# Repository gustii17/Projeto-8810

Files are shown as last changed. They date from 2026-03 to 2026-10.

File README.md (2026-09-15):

# Projeto 8810
`Projeto 8810 - Módulo Didático de Eletrônica Digital`

<h1 align="center">
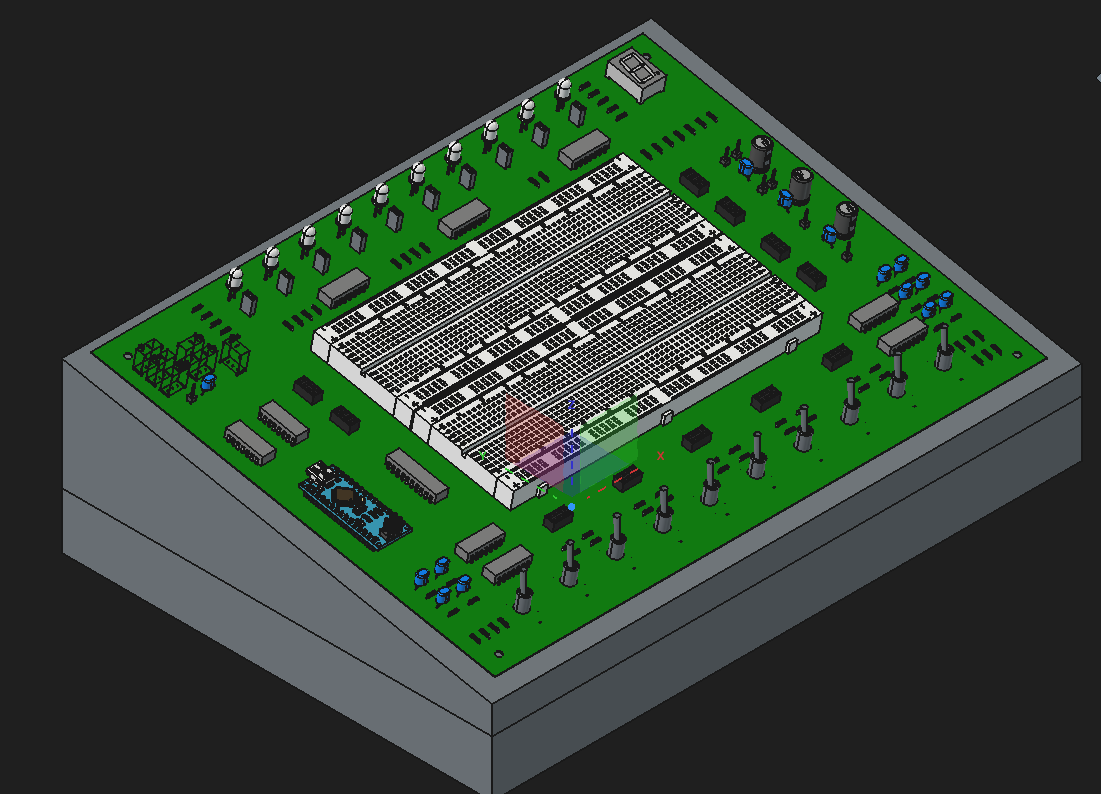
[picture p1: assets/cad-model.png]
  
</h1>

## Sumário 📋
 - [Objetivo](#objective)
 - [Motivação](#motivation)
 - [Projeto](#project)
 - [Arquivos](#files)
 - [Licença](#license)

## Objetivo 🎯
Desenvolver um módulo didático próprio e de baixo custo, capaz de reproduzir as principais funcionalidades do Datapool 8810, incluindo chaves, indicadores LED, protoboard, gerador de clock, ponta de prova e fontes de alimentação.

## Motivação 🚀
A disciplina de Eletrônica Digital é um componente fundamental na formação dos estudantes dos cursos de Engenharia que dependam de eletrônica. As atividades práticas na UFC (Universidade Federal do Ceará) são realizadas com o auxílio do módulo didático Datapool 8810, utilizado para a aplicação dos conceitos estudados em sala de aula. Entretanto, parte desses equipamentos apresenta desgaste e falhas de funcionamento, dificultando a realização dos experimentos. Além disso, os custos de manutenção ou substituição são elevados, evidenciando a necessidade de uma alternativa de baixo custo e de fácil manutenção.

## Projeto 🛠️
O projeto está dividido em basicamente 3 subprojetos, os quais são:
 - A PCB da Placa de Cima, resposável pela lógica e funcionamento geral do módulo, junto com o código do microcontrolador. _[Em Breve](./) mais informações_
 - A PCB da Placa de Baixo, resposável pelo fornecimento de eneriga. _[Clique Aqui](/docs/POWER-BOARD.md) para mais informações_
 - O Modelo 3D do módulo. _[Em Breve](./) mais informações_

## Arquivos 📂

```txt
.
|-- docs/       Documentação e Datasheets
|-- firmware/   Código do microcontrolador
|-- cad/        Modelo 3D
|-- schematics/ Esquemáticos, PCBs e simulações
|-- licenses/   Licenças do projeto
|-- assets/     Imagens
|-- README.md   Este Arquivo
```

## Licença 📝
O Projeto está licenciado sobre algumas licenças da seguinte forma:
 - Todos os arquivos dentro de [cad/](/cad) estão licenciadas sobre a licença [CC By 4.0](/licenses/CC-BY-4.0.txt).
 - Todos os arquivos dentro de [schematics/power-board/](/schematics/power-board) estão licenciadas sobre a licença [CERN OHL P](/licenses/CERN-OHL-P.txt).
 - Todos os arquivos dentro de [firmware/](/firmware) estão licenciados sobre a licença [...]()
 - Todos os arquivos dentro de [schematics/logic-board/](/schematics/logic-board) estão licenciadas sobre a licença [...]()
 - Todos os demais arquivos estão sobre a licença [CC0](/licenses/CC0.txt).

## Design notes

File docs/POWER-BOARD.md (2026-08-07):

# Placa de Energia do Projeto 8810

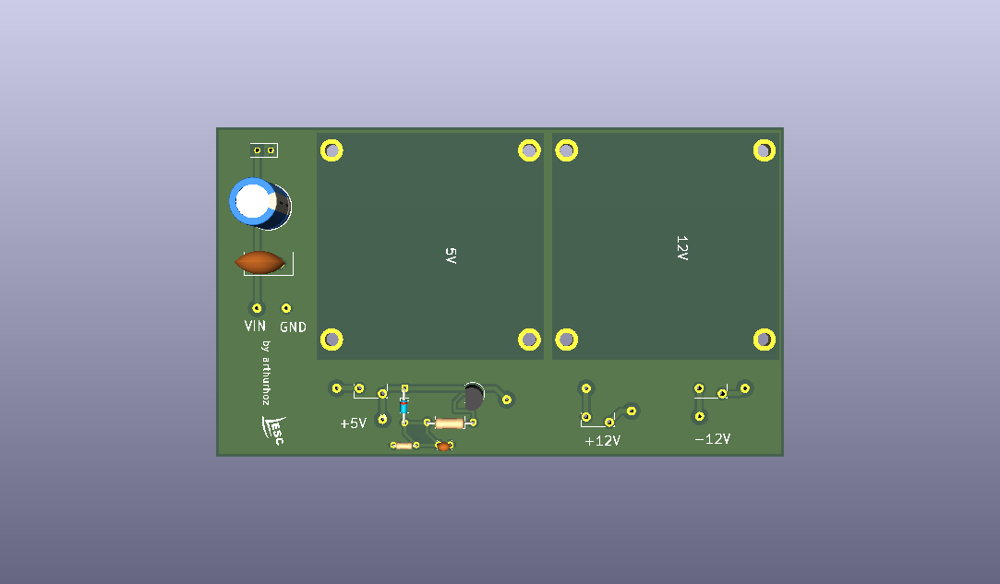
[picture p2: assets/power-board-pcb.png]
Imagem da PCB


## Objetivo
O objetivo da PCB (Placa de circuito impresso) de Energia que ficará dentro do módulo de eletrônica digital desenvolvido é fornecer energia estável para a PCB de cima do módulo, na qual estão localizados a lógica e os componentes que são responsáveis pelas funcionalidades do módulo, além daqueles componentes eletrônicos utilizados pelos próprios usuários.

## Modularidade
Uma das metas do módulo é ser modular, ou seja ter a capacidade de ser utilizado em qualquer lugar que possa fornecer energia, desde que a interface utilizada esteja disponível.
Para isso, decidimos utilizar uma porta USB-C para fornecer energia ao módulo, de modo que podem ser conectados carregadores (seja de notebook ou seja de celular) ou até powerbanks.
No entanto, para que isso funcione o carregador (ou powerbank) deve implementar o USB-C PD (Power Delivery Protocol), um protocolo que permite negociar a tensão estabelecida na porta USB-C, a qual é de 20 V usada nesse projeto.
Portanto, desde que o dispositivo carregador tenha suporte aos 20 V USB-C, o módulo deve funcionar normalmente.

## Por dentro da Placa de Energia
Umas das principais mudanças do módulo da Datapool 8810 © para o desenvolvido aqui na questão da energia, além da porta USB-C, é que o módulo usa conversores DC-DC buck para transformar a tensão recebida (20 V) nas tensões utilizadas (±12 V e 5 V), de modo que a eficiência energética é bem maior e o calor dissipado bem menor que o outro módulo, o qual usa reguladores de tensão lineares. O leitor que estiver interessado em saber mais sobre quais CIs foram utilizados pode buscar pelos esquemáticos disponíveis no repositório.

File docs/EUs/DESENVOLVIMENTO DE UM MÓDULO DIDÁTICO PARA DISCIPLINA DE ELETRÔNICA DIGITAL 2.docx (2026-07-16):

DESENVOLVIMENTO DE UM MÓDULO DIDÁTICO PARA DISCIPLINA DE ELETRÔNICA DIGITAL

Introdução

A disciplina de Eletrônica Digital é fundamental na formação dos estudantes do Departamento de Teleinformática da UFC. Suas atividades práticas utilizam o módulo Datapool 8810 para aplicar os conteúdos estudados. Entretanto, parte desses equipamentos apresenta desgaste, falhas e alto custo de manutenção ou substituição, evidenciando a necessidade de uma alternativa econômica e de fácil manutenção. Desenvolver um módulo didático de baixo custo capaz de reproduzir as principais funcionalidades do Datapool 8810: chaves, indicadores LED, protoboard, gerador de clock, ponta de prova e fontes de alimentação. Trata-se de uma pesquisa aplicada, exploratória e descritiva, iniciada em março de 2026. Foram analisados módulos antigos, consultadas referências e realizadas reuniões com técnicos do laboratório. Em seguida, projetou-se um circuito com Arduino Nano, display de sete segmentos e circuitos integrados como os LM339 e 74HC14. Também foram desenvolvidos o esquemático, a placa de circuito impresso e a estrutura para impressão 3D. Os circuitos foram testados com base em práticas da disciplina, utilizando multímetro e osciloscópio para checar a coerência dos resultados. Foram concluídos a prototipagem, os testes individuais e os modelos iniciais da estrutura 3D e da placa de circuito impresso (PCB). Os testes confirmaram o funcionamento das chaves, LEDs, protoboard, ponta de prova, alimentação e gerador de clock, com tensões e formas de onda compatíveis com o projeto. O custo estimado foi de R$ 1.000,00, aproximadamente metade do valor de um Datapool 8810. Permanecem pendentes a fabricação, a montagem e os testes integrados da placa e da estrutura física. Os resultados preliminares indicam a viabilidade técnica e econômica do módulo proposto. A solução pode contribuir para renovar os equipamentos, reduzir custos e simplificar a manutenção, além de permitir futura adaptação para outros departamentos e instituições.

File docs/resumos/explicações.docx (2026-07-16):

ALIMENTAÇÃO

Existe uma placa por baixo que obtem a energia da tomada e converte em Gnd, 5V, 12V, -12V. então função aqui é obter essas tensões e distribuir para os outros módulos

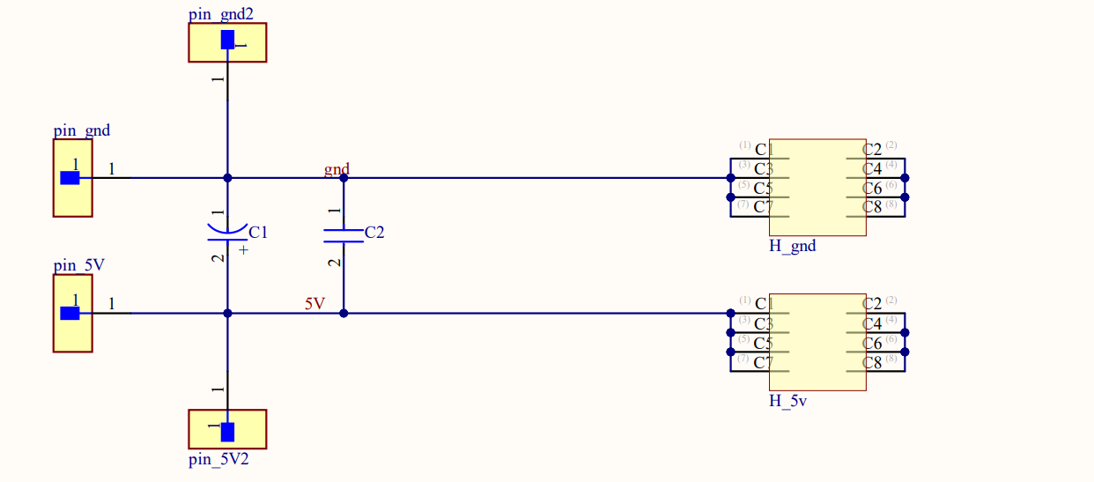
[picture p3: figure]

As 4 seguem o mesmo princípio, chegam em um pino, passa por um capacitor de 100nf para limpar o ruido (tem a possibilidade tanto de eletrolítico como de cerâmica), vão para os restantes dos módulos e para um header 2x4 para os alunos usarem. O gnd e o Vcc tem um pino extra para verificação.

CHAVES

O objetivo das chaves é, uma chave mecânica que fornece sinal logico 1 e 0, e o sinal invertido conforme a posição.

Temos 5v entrando pelo terminal comum da chave, que terá 2 posições, em uma posição ela conecta a saída a 5v, e outra, ela desconecta a saída.

Vamos ter um resistor pull down R1 de 10k para quando a saída estiver desconectada ela ir para 0. Foi feito assim, pois tinha receio que se colocasse na chave algum curto pudesse acontecer.

Temos um capacitor C7 de 100nF para limpara ruido mecânico, e um resistor R3 para evitar danos com o capacitor na comutação.

Essa configuração passa por um inversor schimit triger para debounce e para inverter o sinal tendo a saída invertida, passando por outro para ter a saída normal limpa. no fim, antes de ir para o header para os alunos usados, colocamos resistores de 1k, para caso os alunos façam algum curto circuito com gnd, 5V, 12V ou -12V.

Duvida:

1) esse último resistor pode prejudicar os testes? Considerando que a corrente é pequena
2) O Resistor R3 e o capacitor são realmente necessários?

LEDs

O objetivo é acender o led conforme o sinal

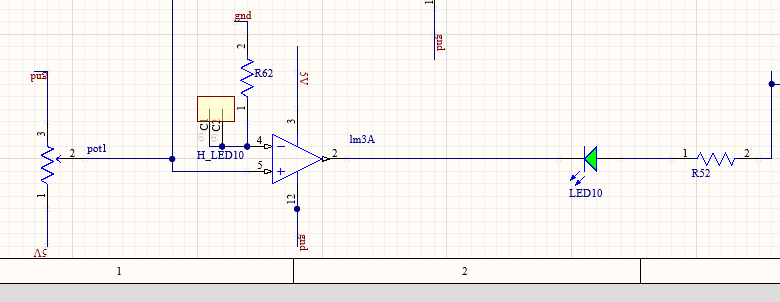
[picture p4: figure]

Os alunos vão colocar o sinal no hearder. E

Esse header terá um resistor pull down R62 para quando estiver desconectado.

Passando pela saída invertida de um comparador lm3A. O comparador irá comparar com 2V, fornecido pelo potenciômetro pot1.

A saída irá para o led, que está já conectado a 5V em serie com um resistor R52. Dessa forma, caso o comparador forneça 0v, o led acenderá, caso forneça 5v (ou desconectado), o led apagará. (note que como o comparador está invertido, isso faz sentido).

PONTA DE PROVA

A ponta de prova tem o objetivo de debug do sistema.

Os alunos tem acesso a uma ponta de prova que podem colocar em algum lugar para verificar a tensão do circuito, e fornecer visualmente, 1 – High, 0 -Low, F – floating, A – indefinido, C - clock (mais que 40Htz)

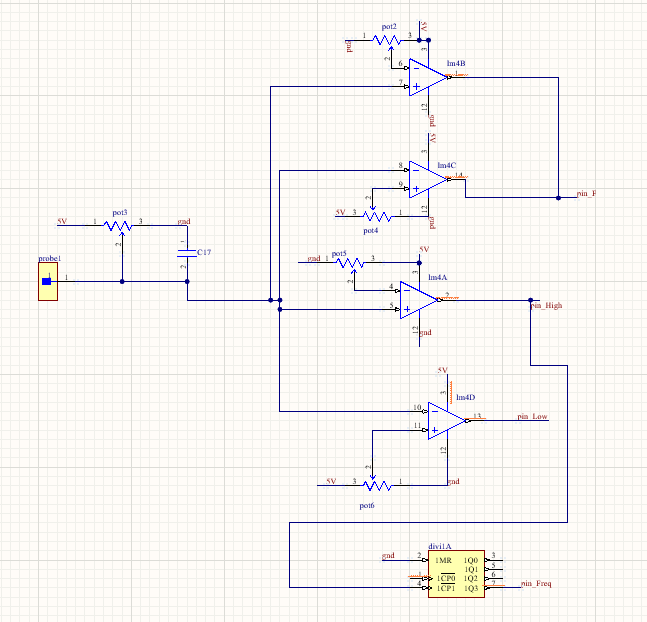
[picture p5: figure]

Parte 1:

A ponta de prova estará fora da placa, mas se ligará a ela por um pino (probe1).

Ele será ligado a um potenciômetro de 100k para fornecer 1.2V caso esteja flutuando. E a Um capacitor para debounce.

Após isso, compararemos a saída para determinarmos o nível de tensão. O lm4B e o lm4c determinando caso esteja no intervalo entre 1.0V e 1.4V está flutuando. O lm4A determina caso esteja mais que 2.0V, está em nível 1. O lm4D determina, caso esteja menor que 0.8V, está em nível lógico 0.

A Saida do lm4A irá para um divisor de década, que servirá para o microcontrolador conseguir detectar 100kHtz de maneira fácil (em testes, as vezes não conseguia). Dividindo a frequência por 5 fica mais fácil.

Esse circuito foi acoplado em um Arduino

Estarei usando um Arduino nano para essa parte, para simplificar o circuito. O Arduino foi escolhido por causa de sua saída de 5V, compatível com a lógica CMOS e TTL. O Arduino é usado para o clock e para a ponta de prova.

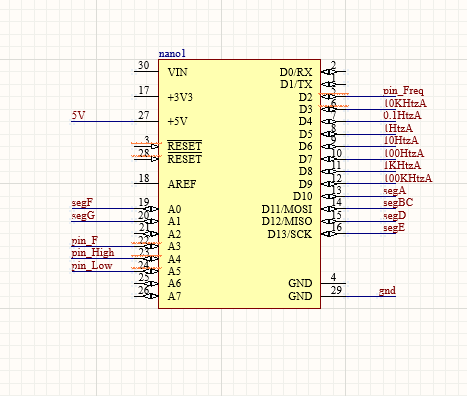
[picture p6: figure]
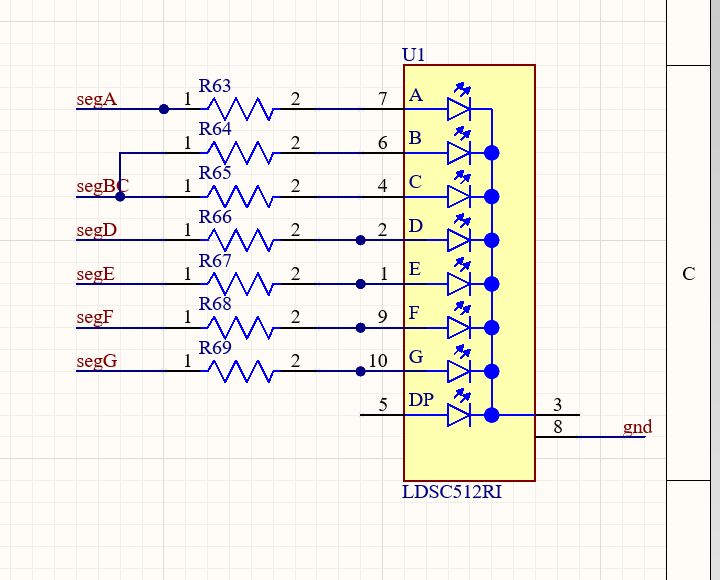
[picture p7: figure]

Parte 2:

O Arduino vai ler a saída dos comparadores, determinar qual o nível de tensão ou se está em frequência, e fornecer para o display de 7 segmentos a saída desejada

O display tem alguns resistores para em serie de 330R para não o queimar. E mostrará a saída conforme a leitura.

CLOCK

O objetivo aqui é fornecer 7 frequências: 100KHtz, 10KHtz, 1KHtzs, 100Htz, 10Htz, 1Htz, 0.1Htz;

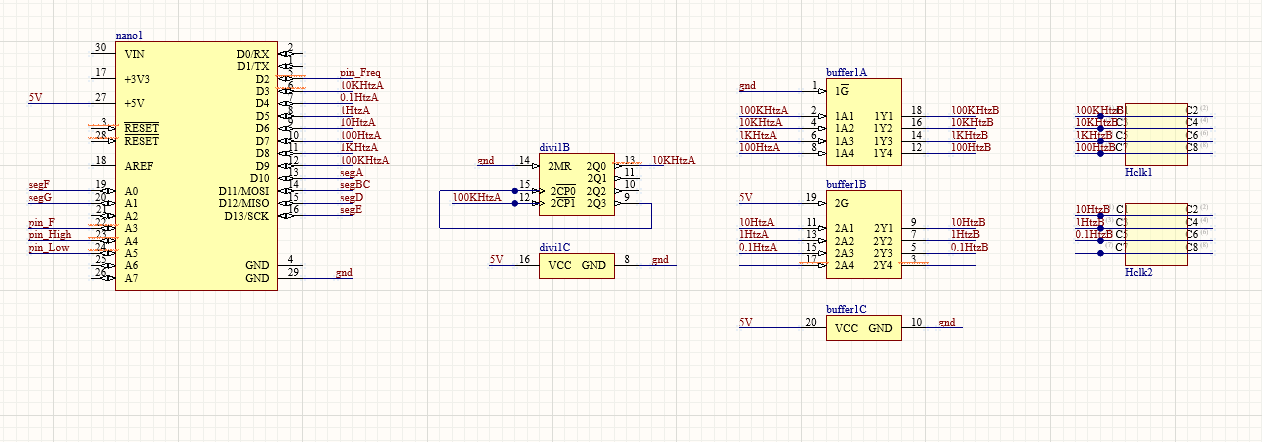
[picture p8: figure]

O Arduino tem 16MHtz, não conseguindo gerar interrupções de 100KHz, então tive que gerar o clock de 100KHtz automaticamente nos registradores, para isso, tenho que usar o pino 9 ou 10. Usei o 9. O problema é que ao gerar a frequência automaticamente ela fica defasada das outras, então para ficarem sincronizadas, usei um divisor década que terá como entrada a frequências de 100kHtz e saída 10kHtz. Como o Arduino consegue gerar interrupções de 10KHtz, agora as outras frequências serão geradas sincronizadas cada uma pela interrupção que o divisor década causa no Arduino.

Para proteger o Arduino de possíveis erros dos alunos, antes de chegar no header, é passado por um buffer, que irá somente passar o mesmo nível de tensão, isolando o Arduino.

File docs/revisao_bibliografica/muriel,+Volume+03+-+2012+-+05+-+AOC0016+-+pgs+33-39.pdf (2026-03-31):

Revista Ilha Digital, ISSN 2177-2649, volume 3, páginas 33 – 39, 2012.

AOC0016 | 33

Artigo disponibilizado on-line

# Revista Ilha Digital

Endereço eletrônico:
http://ilhadigital.florianopolis.ifsc.edu.br/

### MÓDULO DIDÁTICO PARA O ENSINO DE ELETRÔNICA DIGITAL

Mayara de Sousa¹

, Jony Laureano Silveira²

, Leandro Schwarz³

Resumo: Este artigo objetiva demonstrar o desenvolvimento de um kit didático de eletrônica digital desenvolvido para suprir as necessidades das disciplinas de eletrônica digital do IF-SC. Foram realizadas pesquisas pelos equipamentos disponíveis no mercado e reuniões com os professores das disciplinas de modo a levantar as carências e necessidades das soluções comerciais. Com base nestes dados, foi proposto um kit didático de eletrônica digital composto pelos módulos considerados principais.

Palavras-chave: Eletrônica digital. Kit didático. Educação tecnológica.

Abstract: This article demonstrates the development of an educational kit for digital electronics designed to meet the needs of the disciplines of digital electronics at IF-SC. There were carried out researches to know the commercially available solutions. The teachers of the subjects were also consulted in order to identify the requirements of this educational kit. Based on these data, there was proposed a kit containing the modules considered most useful to the digital electronics subject.

Keywords: Digital electronics. Didactic kit. Technology education.

1
Graduanda do Curso Superior de Tecnologia em Sistemas Eletrônicos do DAELN do IFSC <mayarasousa2005@yahoo.com.br>. 2 Professor do DAELN, campus Florianópolis, do IFSC <jony@ifsc.edu.br>. 3
Professor do DAELN, campus Florianópolis, do IFSC <schwarz@ifsc.edu.br>.

### 1. INTRODUÇÃO

A prática e a experimentação em laboratório
são partes importantes do aprendizado dos alunos
(GIL, 2006), em especial nas disciplinas de eletrônica digital dos cursos de tecnologia. Normalmente as práticas são efetuadas através do uso de um equipamento didático (Módulo Digital), o qual possui algumas funções integradas que facilitam a montagem, análise e o entendimento dos experimentos realizados. Entretanto, estes módulos são ferramentas generalistas, possuindo muitas funcionalidades que não são utilizadas durante as disciplinas e, pior, carecendo de outras funções de grande importância para a rápida montagem das atividades sugeridas.
Outro fator bastante limitante é o elevado custo do equipamento, o que impede sua aquisição em quantidades suficientes para os laboratórios; logo, faz-se necessário que os alunos formem grupos de dois a três participantes para a utilização do mesmo módulo. O elevado custo também impede a sua utilização nos períodos extraclasse, bem como sua
disponibilização | nos | almoxarifados | dos

departamentos, onde estes seriam necessários para os testes dos projetos integradores dos alunos. Sendo assim, foi desenvolvido o projeto de um módulo didático para ensino de eletrônica digital de baixo custo e com as funcionalidades que são utilizadas durante as disciplinas.

### 2. FUNDAMENTAÇÃO TEÓRICA

Um sistema digital é um sistema no qual os sinais têm um número finito de valores discretos. Com esta característica, eles são mais fáceis de serem projetados, possuem maior exatidão, são menos afetados por ruídos e são mais adequados à integração. São assim a tecnologia mais utilizada pelos projetistas (TOCCI; WIDMER, 1998).

### 2.1. Módulo didático

O módulo digital consiste no arranjo de blocos lógicos digitais que facilitem a realização dos experimentos solicitados nas disciplinas. As disciplinas de eletrônica digital:
- Lógica Combinacional;
- Lógica Sequencial;
- Dispositivos Lógicos Programáveis;
- Sistemas Digitais.

2.1.1. Datapool 8410
O módulo digital 8410 (Figura 1) é ideal para aplicações básicas de eletrônica digital utilizando circuitos integrados TTL para implementação das funções lógicas do equipamento (DATAPOOL, 2011).

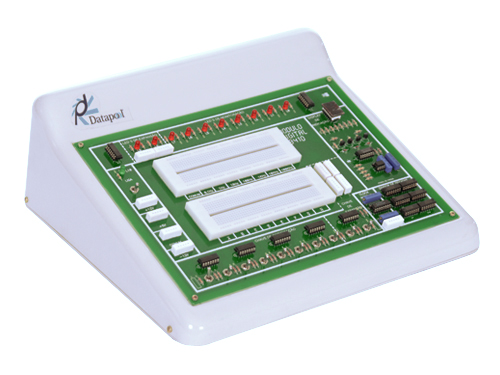
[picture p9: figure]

FIGURA 1 – Módulo digital Datapool 8410.

Fonte: DATAPOOL, 2011.

O Módulo Digital 8410 é equipado com:
- matriz de contatos com 1.100 pontos;
- 10 LEDs de monitoração;
- 10 chaves de entrada de dados do tipo alavanca;
- chave para seleção dos níveis lógicos das chaves para famílias TTL e/ou CMOS;
- gerador de onda quadrada, com saídas compatíveis com TTL e/ou CMOS, nas frequências simultâneas de 100 kHz, 10 kHz, 1 kHz, 100 Hz, 10 Hz, 1 Hz e 0,1 Hz;
- detector de níveis lógicos, com ponta de prova, para níveis lógicos baixo, alto, indeterminado, pulsante e aberto;
- fontes de alimentação protegidas de +5 V (3 A), -12 V (1 A) e +12 V (1 A).

Este módulo é comercializado pelo fabricante por R$ 1.800,00. Juntamente com o módulo, são fornecidos os manuais de operação e manutenção e de teoria e prática.
2.1.2. Datapool 8810
O módulo digital 8810 (Figura 2) é recomendado para aplicações didáticas, em treinamento e aprendizagem dos mais avançados ramos da eletrônica moderna, sendo também um valioso auxiliar no projeto, montagem de testes de circuitos digitais e análogo-digitais (DATAPOOL, 2011).
Próprio para simulações reais, é equipado com matriz de contatos para desenvolvimento e montagens de experimentos, com o manuseio direto dos componentes eletrônicos, objetivando o conhecimento prático destes dispositivos.

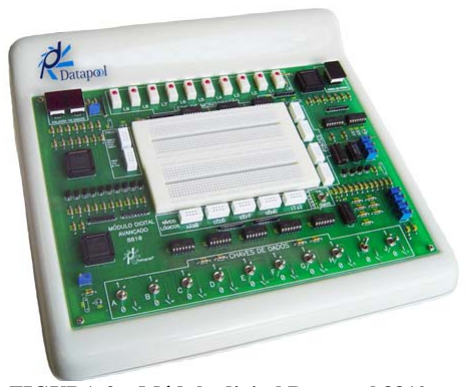
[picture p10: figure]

FIGURA 2 – Módulo digital Datapool 8810.

Fonte: DATAPOOL, 2011.

Ele incorpora fontes de alimentação, circuito decodificador, ponta de prova, chaves e LEDs. Utiliza dispositivos lógicos programáveis e apagáveis (EPLD) para implementação das funções lógicas do equipamento, proporcionando maior confiabilidade.
O Módulo Digital 8810 é equipado com:
- matriz de contatos com 1.100 pontos, para
desenvolvimento | e | montagens | de
experiências;
- fontes protegidas de +5 V (3 A), -15 V (1 A) e +15 V (1 A);
- chave de seleção TTL/CMOS (15 V), que atua sobre todos os sinais do equipamento;
- 10 chaves de entrada de dados, tipo alavanca, que, dependendo de seleção são compatíveis com níveis lógicos TTL e/ou CMOS;
- 10 LEDs de monitoração, para saída de dados;
- 2 | displays/decodificadores | de | sete
segmentos;
- detector de níveis lógicos, com ponta de prova, para níveis lógicos baixo, alto, indeterminado, pulsante e aberto, para a depuração do circuito em teste;
- gerador de onda quadrada, com saídas compatíveis com TTL e/ou CMOS, nas frequências simultâneas de 100 kHz, 10 kHz, 1 kHz, 100 Hz, 10 Hz, 1 Hz e 0,1 Hz.

O módulo 8810 é vendido pelo fabricante por R$ 2.270,00. Juntamente com o equipamento, são fornecidos os manuais de Operação e Manutenção e de Teoria e Prática, além dos componentes para a realização das experiências sugeridas no manual. Opcionalmente, pode ser adquirido o Curso de introdução em Dispositivos Lógicos Programáveis.
2.1.3. EXSTO XD 101
O módulo didático de eletrônica digital XD 101 (Figura 3) possui diversos recursos que permitem a realização de experiências e um melhor aprendizado. Juntamente com o módulo, são fornecidos todos os componentes necessários para a confecção das aplicações propostas no caderno de exercícios além de uma grande área de montagem que permite ao aluno a realização de diversas experiências.

FIGURA 3 – Módulo digital Exsto XD 101.

Fonte: EXSTO, 2011.

O Módulo Digital XD 101 é equipado com:
- fonte de alimentação, bivolt automática; +12 V (1 A), -12 V (1 A), +5 V (3 A) e ajustável de 0 a 12 V (0,5 A), com saídas protegidas contra curto e sobrecorrente;
- relés com contatos C, NA e NF;
- matriz de contatos com 2.200 pontos;
- 10 chaves liga/desliga retentivas NA para simulação de estados lógicos com LED indicador, compatíveis com os CIs TTL;
- 10 LEDs indicadores de estados lógicos compatíveis com a tecnologia TTL;
- 4 displays de sete segmentos;
- chaves pulsativas, sendo um tipo NA e outra tipo NF;
- detector de níveis lógicos, com ponta de prova, para níveis lógicos baixo, alto, aberto, pulsante e indeterminado;
- gerador de nível de tensão TTL e CMOS ajustável de 0 a 12 V;
- gerador de onda quadrada padrão TTL;
- potenciômetro de uso geral.

O preço de mercado para o módulo didáticos da EXSTO modelo XD101 é de R$ 1.650,00.
2.1.4. EXSTO XD 201
O módulo didático de eletrônica digital XD 201 (Figura 4) possui diversos recursos que permitem a realização de experiências e um melhor aprendizado. O módulo possui grande área de montagem que permite ao aluno a realização de diversos experimentos. Esse módulo acompanha também diversos cartões com experiências predefinidas, aumentando assim o aproveitamento do tempo de aula e reduzindo o risco de danos aos componentes.

FIGURA 4 – Módulo digital Exsto XD 201.

Fonte: EXSTO, 2011.

O Módulo Digital XD 201 é equipado com:
- fonte de alimentação:
- matriz de contatos de 1.100 pontos embutida no módulo;
- 2 relés com contatos C, NA e NF;
- 10 chaves liga/desliga retentivas NA para simulação de estados lógicos com LED indicador, compatíveis com os CIs TTL;
- 16 LEDs indicadores de estados lógicos (H, L e tri-state);
- 04 displays de sete segmentos;
- 8 chaves pulsativas sendo quatro baixo ativo e quatro alto ativo;
- 1 buzzer piezoelétrico;
- 2 chaves BCD de dois dígitos;
- 4 potenciômetros de uso geral;
- banco | de | capacitores | cerâmicos | e
eletrolíticos;
- gerador de onda quadrada padrão TTL (0,1 Hz, 0,5 Hz, 10 Hz, 100 Hz, 1 kHz, 10 kHz, 100 kHz e 1 MHz).

O preço de mercado para o módulo didático da EXSTO modelo XD 201 é de R$ 3.150,00.

### 3. MATERIAIS E MÉTODOS

Como o custo dos módulos digitais comerciais é elevado, e estes não possuem todas as funções desejadas, foi, então, desenvolvido um Módulo Didático para o Ensino de Eletrônica Digital.
Para contemplar este objetivo, inicialmente, realizou-se um estudo dos kits didáticos presentes nos laboratórios do IF-SC, com objetivo de verificar quais circuitos fazem parte destes equipamentos e como estes funcionam.
Posteriormente, foi realizada uma consulta nas ementas de eletrônica digital dos cursos do IF-SC e de outras instituições de ensino, verificando-se como são abordados os assuntos referentes à eletrônica digital.
Outra pesquisa realizada focou os kits didáticos para eletrônica digital disponíveis no mercado, visando estudar suas características.
Em posse destes dados, foi realizada uma reunião com os professores de eletrônica digital do DAELN, com objetivo de divulgar a proposta e colher sugestões de melhoria do projeto. Estas informações possibilitaram o desenvolvimento de um plano de trabalho e a descrição das etapas a serem executadas.
A etapa que demandou a maior parte do tempo foi a de projeto e implementação, na qual foram projetados e implementados todos os módulos necessários à composição do modulo didático. Após a implementação, os testes foram
realizados | com | objetivo | de | verificar | o
funcionamento do mesmo.
O diagrama de blocos do equipamento proposto está representado na Figura 5.

FIGURA 5 – Diagrama de blocos do módulo digital proposto.

O Módulo Digital proposto é equipado com:
- fonte de alimentação;
- área de prototipagem;
- fonte de tensão de referência ajustável;
- chaves retentivas;
- LEDs de sinalização;
- decodificadores para display de sete segmentos;
- gerador de frequências;
- ponta de prova.

### 4. RESULTADOS

Na sequência, é apresentado cada um dos módulos projetados.

### 4.1. Fonte de alimentação

A fonte de alimentação para o módulo digital foi concebida de modo a suprir alimentação aos circuitos digitas TTL e CMOS, além de permitir sua utilização para circuitos analógicos, tais como amplificadores operacionais, os quais necessitam de alimentação simétrica. Tendo este contexto em vista, projetou-se uma fonte de alimentação com as tensões +12 V, +5 V, -12 V e -5 V. O layout da placa de circuito da fonte de alimentação projetada está demonstrado na Figura 6.

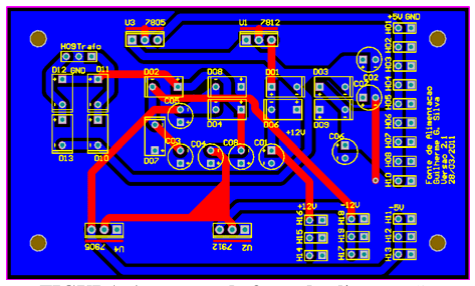
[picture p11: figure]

FIGURA 6 – Layout da fonte de alimentação
do módulo digital desenvolvido.

A fonte é constituída de um transformador 220-110 V / 15+15 V (1 A), um circuito retificador formado por quatro diodos em configuração ponte completa, dois capacitores para diminuição do ripple e quatro reguladores de tensão (7805, 7812, 7905, 7912).

### 4.2. Área de prototipagem

A área de prototipagem é composta por duas matrizes de contatos de 640 contatos cada (totalizando 1280 contatos) posicionada acima das chaves e abaixo dos LEDs e displays, de modo a permitir a rápida montagem dos circuitos para teste em sala de aula.

### 4.3. Fonte de tensão de referência ajustável

De modo a proporcionar um melhor entendimento das tensões de nível lógico e da rejeição ao ruído dos sistemas digitais, além da possível utilização como referência de tensão para o circuito analógico, foi implementada uma fonte de tensão de referência ajustável na faixa de 0 a 18 V. A fonte possui dois potenciômetros para ajuste, sendo um para o ajuste grosso da tensão e outro para o ajuste fino (MALVINO; LEACH, 1987). O layout da placa do circuito projetado está demonstrado na Figura 7.

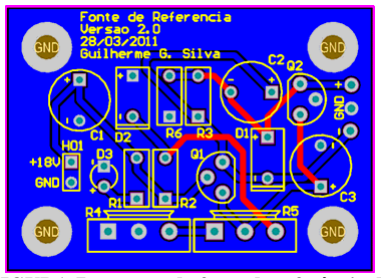
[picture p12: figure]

FIGURA 7 – Layout da fonte de referência de tensão ajustável do módulo digital desenvolvido.

### 4.4. Chaves retentivas

A entrada de dados é feita através de um barramento de chaves retentivas. As chaves retentivas comutam de nível lógico a cada acionamento e o mantêm até que a chave seja acionada novamente. O módulo digital foi composto de 10 chaves retentivas; todas possuindo sistema antirrepique, saída complementar e LEDs bicolores indicativos de estado lógico. O circuito antirrepique das chaves foi composto por portas NAND em configuração latch SR (TOCCI; WIDMER; MOSS, 2007). Os LEDs bicolores permitem a indicação visual do nível lógico da chave, sendo escolhida a cor vermelha para o nível lógico baixo e verde para o nível lógico alto. O layout do circuito impresso encontra-se na Figura 8.

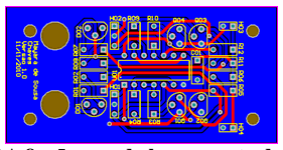
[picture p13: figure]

FIGURA 8 – Layout do barramento de chaves retentivas do módulo digital desenvolvido.

### 4.5. Barramento de LEDs de monitoração

A saída de dados é composta por dois blocos: o barramento de LEDs indicativos e displays de sete segmentos. O bloco de LEDs indicativos é formado por 10 LEDs que indicam os estados lógicos compatíveis com níveis TTL. Os LEDs possuem portas inversoras de modo a acender drenando corrente para a porta inversora. Os circuitos integrados TTL, devido ao estágio de saída totem-pole, permitem maior fluxo de corrente da saída em nível lógico baixo (dreno) que em nível lógico alto (fonte), permitindo, portanto, melhor acendimento neste modo (MENDONÇA; ZELENOVSKY, 2004). O layout do circuito está demonstrado na Figura 9.

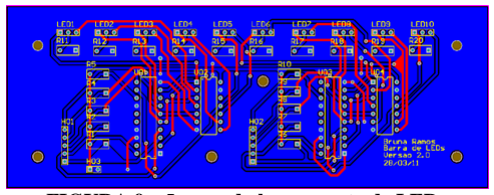
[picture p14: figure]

FIGURA 9 – Layout do barramento de LEDs de monitoração do módulo digital desenvolvido.

### 4.6. Bloco de displays de sete segmentos

O bloco de displays de sete segmentos é composto por dois displays de sete segmentos dotados de decodificadores BCD para sete segmentos. Este bloco permite ao aluno testar rapidamente a operação de contagem de contadores binários e BCDs, multiplicação e divisão por dois através de registradores de deslocamento e Unidades Lógico-Aritméticas (ULAs). O circuito foi dotado de decodificadores, blocos de espera para conexão com o barramento de dados (D0, D1, D2 e D3), espera para controle (RBI, RBO), espera para o ponto decimal e botão pulsátil para testes dos displays (LT) (SZAJNBERG, 1988). O layout da placa de circuito impresso referente a este bloco pode ser visualizado na Figura 10.

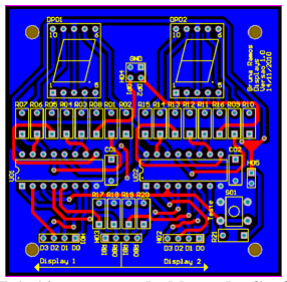
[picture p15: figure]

FIGURA 10 – Layout do bloco de displays de sete segmentos do módulo digital desenvolvido.

### 4.7. Gerador de frequências

O gerador de frequências foi implementado utilizando-se um CI 555 e dois 74390. O 555 é um circuito integrado circuito composto de um flip-flop do tipo SR, dois comparadores simples e um transistor de descarga. Projetado para aplicações gerais de temporização, é um integrado de fácil aquisição no mercado de componentes eletrônicos. O CI 555 é responsável por produzir a maior frequência do gerador, 10 kHz. Para tanto, faz-se necessário utilizá-lo na topologia astável, conforme ilustrado na Figura 11.

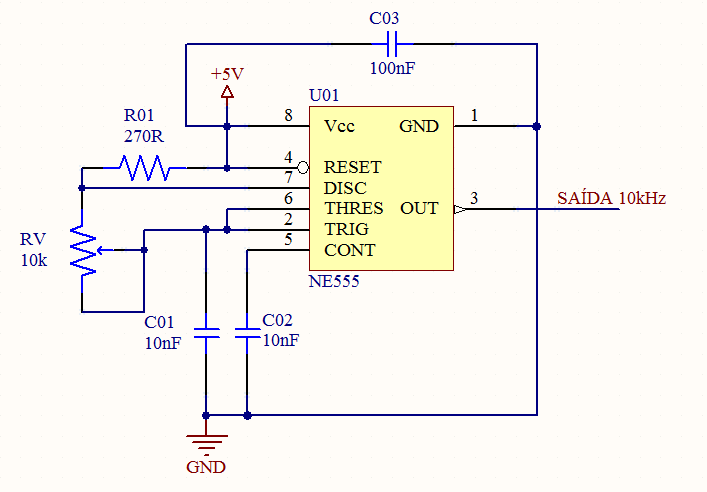
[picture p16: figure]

FIGURA 11 – 555 em topologia astável para gerar a frequência de 10 kHz.

O potenciômetro inserido no circuito é utilizado para ajustar a frequência de saída com maior precisão, uma vez que esta depende dos valores dos capacitores e resistores do circuito.
O 74390 é um contador de décadas crescente, formado por dois módulos independentes no mesmo circuito integrado. O contador foi implementado em modo biquinário para permitir uma forma de onda de saída com ciclo ativo de 50%.
A frequência gerada pelo 555 foi injetada no primeiro divisor de décadas para produzir a frequência de 1 kHz; esta, por sua vez, foi injetada em outro divisor para produzir a de 100 Hz, e assim sucessivamente para as demais frequências de 10 Hz e 1 Hz.
Foram, portanto, utilizados dois CIs 74390 para gerarem os quatro sinais de clock diferentes, conforme ilustrado nas Figuras 12(a) e 12(b).

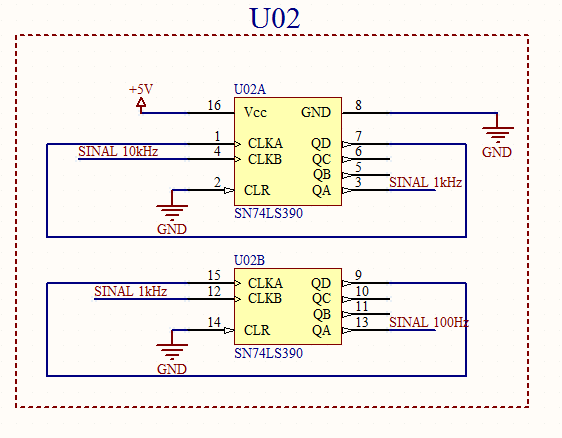
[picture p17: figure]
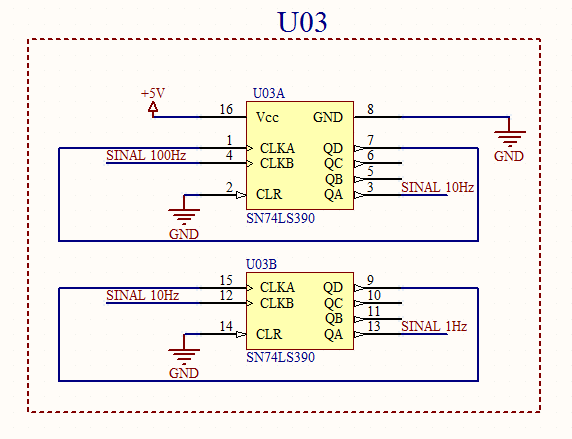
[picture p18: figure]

(a) (b)
FIGURA 12 – Divisores de décadas para as frequências de (a) 1 kHz e 100 Hz e (b) 10 Hz e 1 Hz.

O layout da placa de circuito impresso do
gerador de frequências está apresentado na
Figura 13.

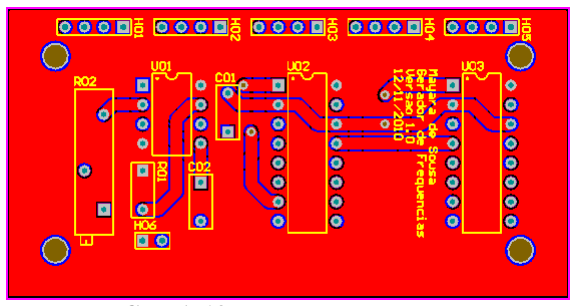
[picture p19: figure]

FIGURA 13 – Layout do gerador de frequências do módulo digital desenvolvido.

### 4.8. Protótipo desenvolvido

Para a construção do protótipo, foi utilizado um gabinete de madeira em forma de caixa com tampa levemente inclinada. Apesar de a madeira não ser o material adequado para a construção do módulo digital, este material foi escolhido em caráter experimental, devido ao baixo custo e facilidade de usinagem. Recomenda-se fortemente que, na possibilidade de replicação destes módulos, seja utilizado um gabinete de plástico antichamas com design ergonômico.
A fonte de alimentação, a fonte de tensão de referência ajustável, os módulos de chaves retentivas e o módulo de LEDs de sinalização foram acomodados no interior do gabinete, sendo disponibilizados conectores na tampa. O gerador de frequências e o módulo de dois displays de sete segmentos foram parafusados na tampa, ao lado da área de prototipagem.
A ponta de prova não funcionou conforme o esperado e, portanto, ela não foi incluída nesta versão do módulo digital. A foto do protótipo desenvolvido pode ser visualizada na Figura 14.

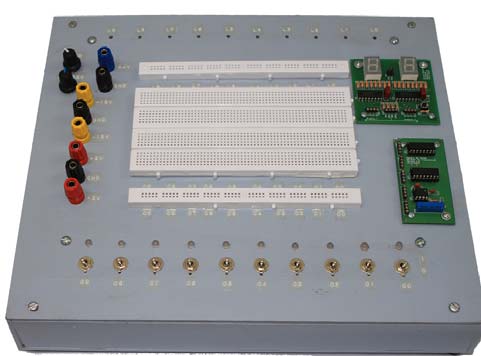
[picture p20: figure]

FIGURA 14 – Protótipo desenvolvido.

### 5. CONSIDERAÇÕES FINAIS

O estudo realizado com os módulos comerciais mostrou que estes são compostos basicamente pelos mesmos blocos funcionais. Constatou-se que a maior parte dos experimentos clássicos das disciplinas de eletrônica digital pode ser realizada com estes blocos.
Foi desenvolvido um kit didático contendo os elementos considerados prioritários para a maior parte dos experimentos clássicos das disciplinas de eletrônica digital dos cursos do IF-SC.
O módulo digital foi construído com componentes facilmente encontrados no comércio varejista, de modo que o protótipo mostrou-se uma alternativa viável de reprodução. É preciso salientar que o custo da montagem em série ou a construção de um número elevado de módulos não foram estudados, bem como o desenvolvimento de um gabinete plástico ergonômico específico. REFERÊNCIAS
DATAPOOL. | Disponível | em: | <http://www.
datapool.com.br> Acesso em: 08 de jan. de 2011. EXSTO. Disponível em <http://www.exsto.com.br> Acesso em: 10 de jan. de 2011.
GIL, A. C. Didática do ensino superior. São Paulo: Atlas, 1ª ed., 256 p., 2006.
MALVINO, A. P.; LEACH, D. P. Eletrônica digital: princípios e aplicações. São Paulo: McGraw-Hill, 1ª ed, v. 2, 675 p., 1987.
MENDONÇA, A.; ZELENOVSKY, R. Eletrônica digital: curso prático e exercícios. Rio de Janeiro: MZ Editora, 2004. 580 p.
SZAJNBERG, M. Eletrônica digital. Rio de Janeiro: LTC Editora, 1988. 395 p.
TOCCI, R. J.; WIDMER, N. S. Sistemas digitais: princípios e aplicações. 7ª ed. Rio de Janeiro: LTC Editora, 1998. 910 p.
TOCCI, R. J.; WIDMER, N. S.; MOSS, G. L. Sistemas digitais: princípios e aplicações. 10ª ed. São Paulo: Editora Pearson/ Prentice Hall, 2007. 830 p.

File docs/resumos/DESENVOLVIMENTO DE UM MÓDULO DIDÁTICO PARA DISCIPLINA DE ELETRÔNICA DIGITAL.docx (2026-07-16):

DESENVOLVIMENTO DE UM MÓDULO DIDÁTICO PARA DISCIPLINA DE ELETRÔNICA DIGITAL

Introdução

A disciplina de Eletrônica Digital é um pilar formador na matriz curricular dos cursos do Departamento de Teleinformática (DETI). Nesse contexto, a disciplina contempla atividades práticas realizadas com o auxílio do módulo didático Datapool 8810, que é o primeiro contato dos alunos com os conceitos de eletrônica. Entretanto, muitos desses módulos são antigos e estão desgastados, resultando em falhas durante as práticas, o que dificulta a execução dos testes e desmotiva estudantes e professores. Esse problema é agravado pelos altos custos de substituição desses módulos.

Objetivo

Esse estudo busca descrever o desenvolvimento de um módulo didático próprio e de baixo custo para substituir os módulos danificados do laboratório da universidade.

Metodologia

Trata-se de uma pesquisa aplicada, de caráter exploratório e descritivo, realizado desde março a julho de 2026. A primeira etapa do desenvolvimento se deu com base na análise dos módulos antigos, em pesquisas bibliográficas e em reuniões com os técnicos responsáveis pelos equipamentos no DETI. A segunda etapa foi o projeto de um novo circuito usando Arduino e circuitos integrados para compor as funcionalidades do módulo original. A terceira etapa foi o desenvolvimento de uma placa de circuito impresso e de uma estrutura em impressão 3D para a montagem física do equipamento.

Resultados

A etapa atual é o desenvolvimento de um protótipo funcional. O projeto segue em testes, os quais indicam que o equipamento é capaz de reproduzir as funcionalidades propostas. Após a montagem física, o protótipo seguirá para as etapas de avaliação e aperfeiçoamento.

Conclusão

Por fim, o projeto apresenta perspectivas promissoras para a revitalizar os equipamentos do laboratório por meio dos próprios alunos da Universidade Federal do Ceará. Além disso, a proposta também demonstra possibilidade de expansão para demais departamentos ou universidades com disciplinas correlatas.

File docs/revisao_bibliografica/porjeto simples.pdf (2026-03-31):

Projeto de módulos simples para aulas práticas do laboratório de eletrônica digital – portas lógicas

Alcides J. G. Carneiro [1], Francisco A. Filho [2], Thatiane B. Felix [3], Éwerton R. S. Castro [4]
[1] alcides.jose@academico.ifpb.edu.br, alves.francisco@academico.ifpb.edu.br [2] , thatiane.felix@academico.ifpb.edu.br [3] , ewerton.castro@ifpb.edu.br[4]

Resumo
O projeto teve o desenvolvimento e construção de kits de experimentos de laboratório para as aulas das disciplinas de Eletrônica Digital e Sistemas Digitais, especialmente para as aulas de portas lógicas, a um custo mais baixo que os módulos utilizados. Os módulos têm como objetivo o aumento na quantidade de equipamentos nos laboratórios, um por aluno. Um protótipo foi construído e a partir dele foi realizado a cotação, junto a diversos sites de fornecedores, de todos os itens necessários para construção dos kits do laboratório. Utilizando os recursos do projeto, realizou-se compra, pagamento e rastreamentos da entrega de todos os itens. Após os itens chegarem, cada um foi testado para possível devolução e troca. Em seguida, foram separados, os itens que compõem cada kit de experimento para montagem dos módulos. E nova fase de testes dos componentes para possíveis substituições. Foram preparados materiais explicativos dos kits em vídeos tutoriais para atividades práticas em laboratório.
Palavras-chave: Portas Lógicas, Kits de experimentos, Laboratório.

Abstract
The project had the development and construction of laboratory experiment kits for classes in the disciplines of Digital Electronics and Digital Systems, especially for the classes of logic gates, at a lower cost than the modules used. The modules aim to increase the amount of equipment in the laboratories, one per student. A prototype was built and from it a quotation was made, along with several supplier sites, of all the items necessary for the construction of the laboratory kits. Using the project's resources, purchase, payment and delivery tracking of all items were carried out. After the items arrived, each was tested for possible return and exchange. Then, the items that make up each experiment kit for assembling the modules were separated. And a new phase of testing the components for possible replacements. Explanatory materials for the kits were prepared in tutorial videos for practical laboratory activities.
Keywords: Logic Gates, Experiment Kits, Laboratory.

### 1 Introdução

Os cursos do IFPB têm como diferencial a integração dos conteúdos teóricos e práticos. Esses conteúdos são ministrados e aplicados utilizando equipamentos e dependências dos laboratórios. Assim, a qualidade e o aprendizado dos alunos dependem da quantidade de atividades práticas realizadas em laboratório. Então, laboratórios bem equipados e com números compatíveis a quantidade de alunos das turmas, melhora consideravelmente a experiência e o processo de aprendizado. No entanto, a quantidade de alunos que entram nos cursos integrados e subsequentes vê crescendo ano a ano. Esse número crescente, gera a necessidade de um maior número de equipamentos nos laboratórios para não comprometer o desempenho acadêmico. Sendo assim, o aumento de equipamentos nos laboratórios para atender essa demanda de alunos se reflete na necessidade de novos investimentos que, dependendo dos itens a serem adquiridos, atingem altos valores.

Por fim, a obtenção de equipamentos a um baixo custo simplifica a aquisição e atende a demanda dos alunos e professores nas aulas práticas das disciplinas de Eletrônica Digital e Sistemas Digitais, nos conteúdos que envolvem aulas práticas com portas lógicas.

### 2 Referencial teórico

As disciplinas de Eletrônica Digital (IDOETA, GARCIA, MALVINO) e Sistemas Digitais (TOCCI), ministradas nos cursos integrado e subsequente em Eletrotécnica e no curso subsequente de Manutenção de Suporte em Informática respectivamente descritas
e | previstas | nos | seus | PPCs | (PROJETO
PEDAGÓGICO DE CURSO) têm parte de suas atividades e avaliações feitas em laboratório (PPC-ELETROINT , PPC-ELETROSUB, PPC-MSI). No entanto, a quantidade de alunos que concorrem nos cursos integrados e subsequentes em Eletrotécnica e no curso subsequente de Manutenção de Suporte em

Informática no campus Patos veem crescendo ano a ano (PSCT—IFPB - Processo Seletivo para os Cursos Técnicos do IFPB, 2018.1 à 2021.1). Esse número crescente precisa de um maior número de equipamentos nos laboratórios para não comprometer o desempenho acadêmico (PPC-ELETROINT, PPC-ELETROSUB, PPC-MSI). O aumento no número de equipamentos do laboratório para atender a demanda crescente de alunos se reflete na necessidade de novos investimentos que, dependendo dos itens a serem adquiridos, atingem altos valores. Em consulta feita junto ao fornecedor do módulo digital avançado -Datapool em 12/junho/2019 (DATAPOOL), o custo de cada módulo é de aproximadamente R$ 3.500,00 -três mil e quinhentos reais. No entanto, verifica-se que para as atividades práticas das disciplinas citadas, muitas das funcionalidades avançadas, do módulo citado, não são utilizadas. Ou seja, um módulo digital mais simples seria suficiente para as principais atividades práticas realizadas. Verificou-se que o custo de produção desses módulos (ou kits) mais simples ficam extremamente baixo. Tão baixo que com o valor desse projeto R$ 3.500,00 (três mil e quinhentos reais, ou seja, o valor de um único módulo) é suficiente para construir 50 (cinquenta) kits ou módulos mais simples para o laboratório (consulta realizada dos itens para construção do kit junto a diversos sites de fornecedores), além de acrescentar equipamentos e peças de reserva.

### 3 Método da pesquisa

Este projeto foi dividido em seis etapas. A etapa 1 teve início com a listagem dos itens que compõem o kit do laboratório proposto. Um protótipo já foi construído e cotações de preços, junto aos sites de fornecedores, de todos os itens necessários para construção dos kits, foram realizadas. Na etapa 2 foi feito a compra, pagamento e rastreamentos da entrega de todos os itens dos kits que foram construídos. Na terceira etapa, quando os itens comprados chegaram, cada um deles foi testado para possível devolução e troca junto ao fornecedor. Em seguida, foram separados, os itens que compõem cada kit para montagem dos módulos. Na etapa seguinte (4), foi realizado a montagem de cada um dos kits. Após a montagem, nova fase de testes dos componentes para possíveis substituições. Na quinta etapa, foram preparados materiais explicativos dos kits (uma apostila em pdf) e vídeos tutoriais (postados no youtube). Na etapa final, foi entregue os pequenos módulos no laboratório com os kits liberados para utilização em aulas práticas. O projeto teve a participação de três alunos do curso subsequente em

Eletrotécnica, um aluno como voluntário e dois bolsistas.

### 4 Resultados da pesquisa

O projeto foi divido em seis etapas e em cada uma delas, se obteve resultados que facilitaram o acompanhamento do mesmo.

Etapa 1: Um protótipo (Figura 1) foi construído e a partir dos itens que o compõem (Quadro 1), foi realizado cotações, junto aos sites de diversos fornecedores de componentes, para aquisição da quantidade de componentes para construção de 50 (cinquenta) módulos simples para aulas práticas do laboratório de eletrônica digital com foco no assunto de portas lógicas.

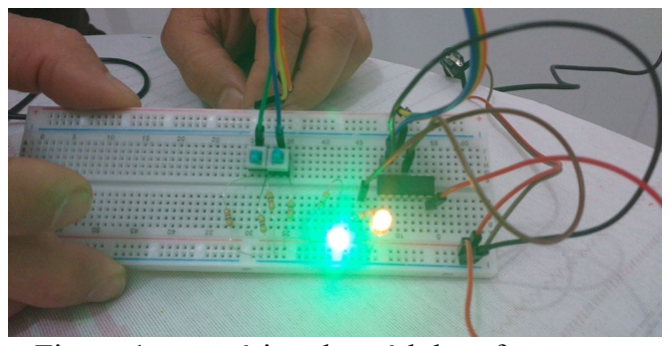
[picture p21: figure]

Figura 1 – protótipo do módulo – fonte: autor

Quadro 1 – Itens que compõem cada módulo

ITEM | Quantidade
Protoboard 830 pontos | 1
Chave táctil com trava 7x7 6T | 4
Cabo Dupont jumper MxM | 1
Led difuso vermelho 5mm | 1
Led difuso verde 5mm | 1
Resistor CR25 1/4w 390 ohms | 2
Resistor CR25 1/4w 4,7k ohms | 8
Fonte chaveada 5V/1A | 1
Porta Lógica CD4081 AND | 1
Porta Lógica CD4071 OR | 1
Porta Lógica CD4011 NAND | 1
Porta Lógica CD4001 NOR | 1
Porta Lógica CD4069 NOT | 1
Porta Lógica CD4030 XOR | 1
Porta Lógica CD4081 NXOR | 1
Fonte: Elaboração própria.

Etapa 2: Nessa etapa foi realizado a compra, pagamento e rastreamentos da entrega de todos os itens dos módulos que foram construídos (Figura 2).

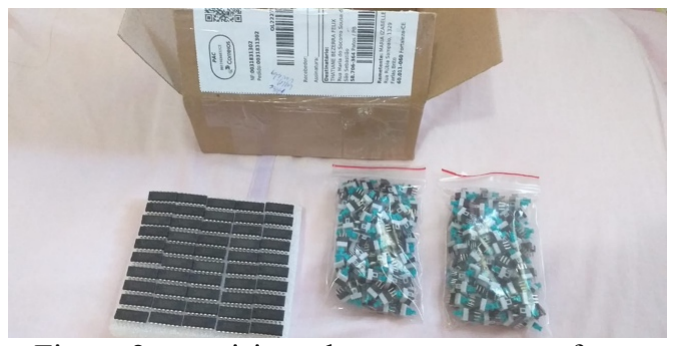
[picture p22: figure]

Figura 2 – aquisição de componentes – fonte: autor

Etapa 3: Quando os itens comprados chegaram, cada um foi testado para possível devolução e troca junto ao fornecedor. Em seguida, foram separados, os itens que compõem cada kit para montagem dos módulos (Figura 3).

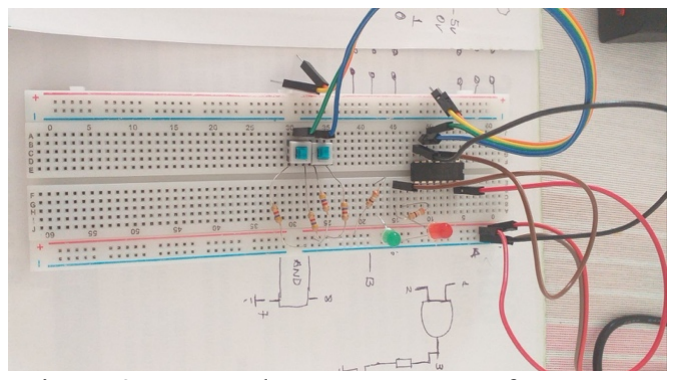
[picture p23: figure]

Figura 3 – testes de componentes – fonte: autor

Etapa 4: Aqui foi feita a montagem de cada um dos kits. Após a montagem, nova fase de testes dos componentes para possíveis substituições (Figura 4).

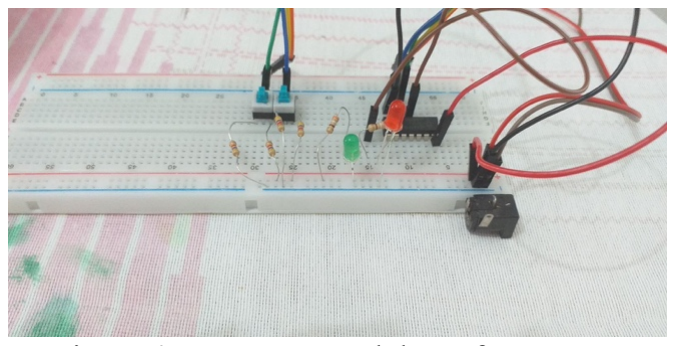
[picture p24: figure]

Figura 4 – testes os módulos – fonte: autor

Etapa 5: Nessa etapa foram preparados materiais explicativos dos kits (Figura 5), vídeos tutoriais (Figura 6) e preparação de material para auxiliar as atividades práticas em laboratório (Figura 7).

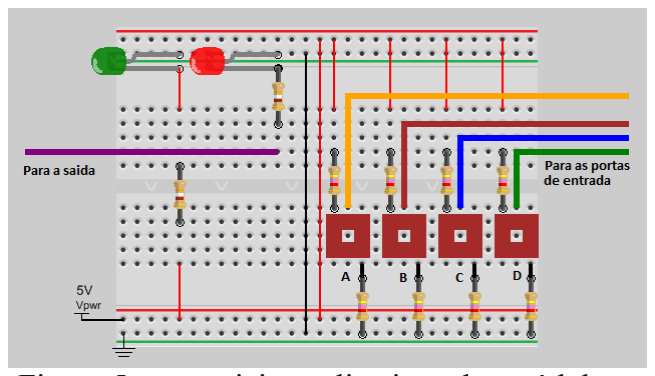
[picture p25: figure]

Figura 5 – materiais explicativos dos módulos – fonte: autor


Figura 6 – vídeos tutoriais dos módulos – fonte: autor


Figura 7 materiais auxiliares as práticas de laboratório – fonte: autor

Etapa 6: Na etapa final foi a entrega (Figura 8 e
9) no laboratório dos módulos para utilização nas disciplinas em aulas práticas.


Figura 8 módulos prontos – fonte: autor


Figura 9 módulos entregues no laboratório e prontos para uso nas aulas práticas sobre o uso de portas lógicas – fonte: autor

### 5 Conclusão/Considerações

Verificou-se que o custo de produção desses
módulos | (ou | kits) mais | simples | ficaram
extremamente baixo. Tão baixo que com o valor desse projeto R$ 3.500,00 (três mil e quinhentos reais) foi suficiente para construir 50 (cinquenta) kits ou módulos mais simples para o laboratório (valor que é aproximadamente o mesmo de um único módulo completo da Datapool).

Assim, graças ao esforço e empenho de todos os alunos envolvidos no projeto, um voluntário e dois bolsistas, foi possível construir a partir de um protótipo, cinquenta (50) módulos digitais mais simples que são suficientes para as principais atividades práticas realizadas com portas lógicas das disciplinas de Eletrônica Digital e Sistemas Digitais, ministradas nos cursos integrado e subsequente em Eletrotécnica e no curso subsequente de Manutenção de Suporte em Informática.

Esse projeto só foi possível, graças ao apoio financeiro do IFPB (Interconecta IFPB Edital Nº 20/2020), do empenho da coordenação de pesquisa e da gestão do IFPB campus Patos.

Referências

DATAPOOL, Módulo 8810 Eletrônica, Disponível em:
http://eletronica.datapool.com.br/produtos/eletroeletronica/modulo-8810/
Acesso em: 23/03/2021

IDOETA, Ivan V. et al. Elementos de eletrônica digital. Érica, 2008.

GARCIA, Paulo A., MARTINI, José S. C. Eletrônica Digital –Teoria e Laboratório. Érica. 2007.

MALVINO, A. Paul, Microcomputadores e Microprocessadores. McGraw-Hill. 1985.

PPC-ELETROSUB - PPC do Curso de Eletrotécnica-Subsequente, Disponível em: https://estudante.ifpb.edu.br/media/cursos/61/documentos/PPC_Eletrotécnica_Subsequente_IFPB-Patos.pdf Acesso em: 23/03/2021

PPC-ELETROINT -PPC do Curso de Eletrotécnica -Integrado – Disponível em: https://estudante.ifpb.edu.br/media/cursos/111/documentos/PPC_Eletrotécnica_Integrado_IFPB-Patos_8kyLsMi.pdf Acesso em: 23/03/2021

PPC-MSI – PPC do Curso de Mautenção e Suporte em Informática, Disponível em: https://estudante.ifpb.edu.br/media/cursos/63/documentos/PPC_CTSMSI_Patos_Subsequente_-_VERSÃO_FINAL_novo_41UYFcc.pdf
Acesso em: 23/03/2021

PSCT-IFPB Disponível em:
https://estudante.ifpb.edu.br/processoseletivo/processo/1/edicoes/ , Acessado em: 23/03/2021

TOCCI, Ronald J. et Al. Sistemas Digitais – princípios e aplicações 11ª edição. Pearson Education do Brasil. 2011.

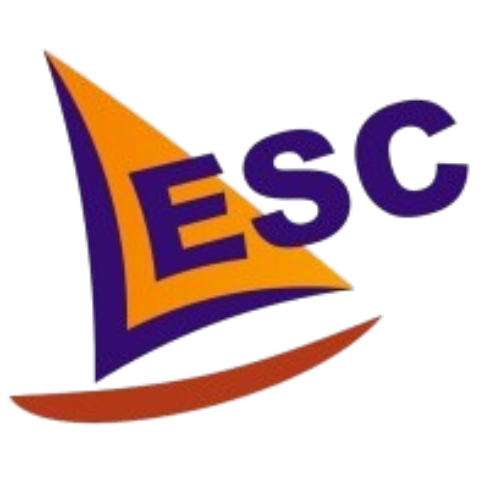
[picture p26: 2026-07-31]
schematics/logic-board/pcb/placa de cima/docs/transferir.png

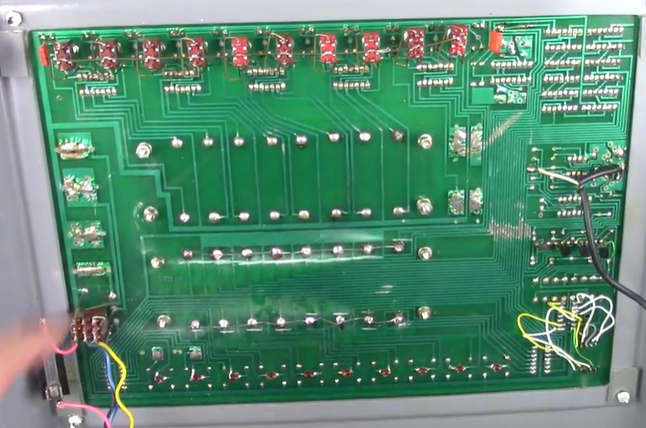
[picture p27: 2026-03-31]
docs/fotos/placa 8410 por baixo.png

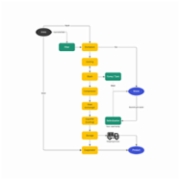
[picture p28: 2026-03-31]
docs/organização/no miro_files/size180.jpg

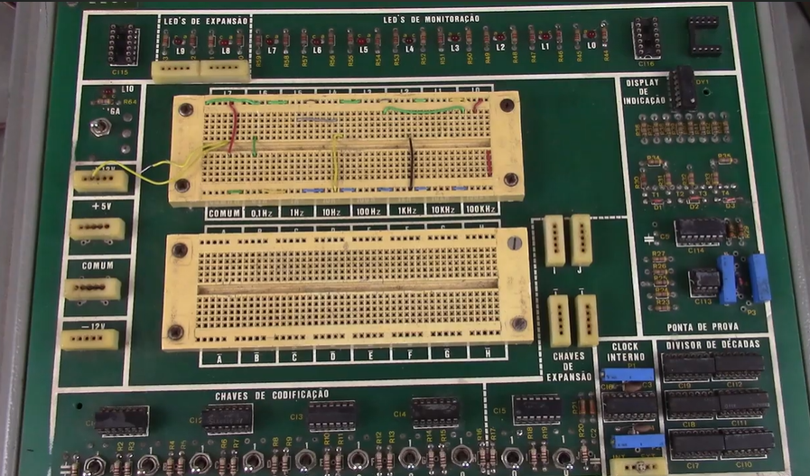
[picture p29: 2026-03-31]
docs/fotos/placa 8410 por cima.png

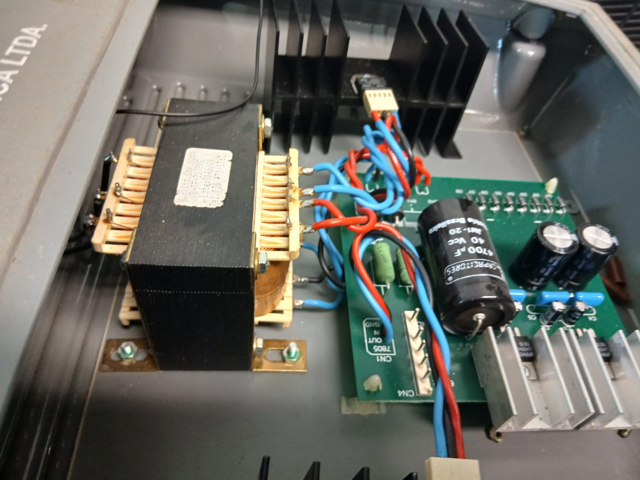
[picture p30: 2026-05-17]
docs/fotos/modulo 8810/transformdor.jpeg

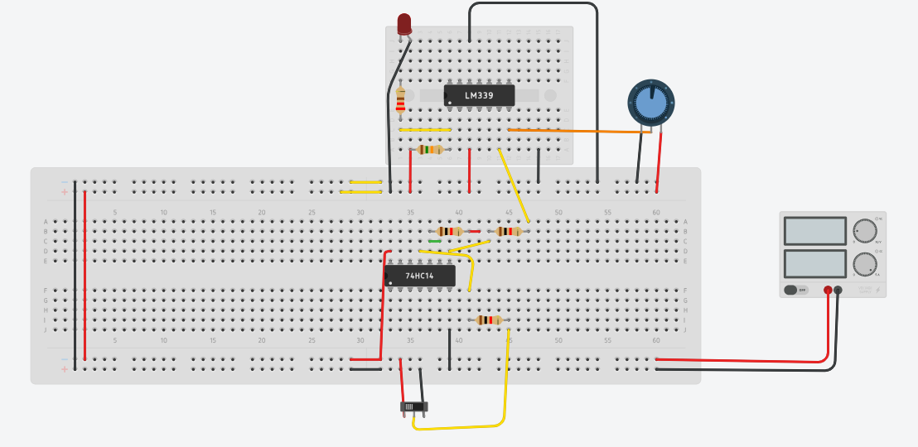
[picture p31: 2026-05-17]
assets/partes/led/comparador no led.png

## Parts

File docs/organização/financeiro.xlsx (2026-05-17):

componente | quantidade | link de compra | local de compra | prioridade | preço por unidade | preço total | total(acumulado)
lm339 | 5 | link (https://www.digikey.com.br/pt/products/detail/rochester-electronics-llc/LM339AN/15638671) | digikey | alta | 1.2 | 6 | 6
74hct14 | 6 | link (https://www.digikey.com.br/pt/products/detail/texas-instruments/SN74HCT14N/376852) | digikey | alta | 4 | 24 | 30
chave | 10 | link (https://www.smartkits.com.br/chave-alavanca-mts-102-de-2-posicoes) | smartkits | alta | 4.9 | 49 | 79
barra de pinos | 3 | link (https://www.smartkits.com.br/barra-de-pinos-femea-2x40-180-graus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) | smartkits | alta | 1.9 | 5.7 | 84.7
protoboard 760 pinos | 2 | link (https://www.autocorerobotica.com.br/protoboard-760-pontos) | autocore | media | 18.9 | 37.8 | 122.5
74hct390 | 3 | link (https://www.digikey.com.br/pt/products/detail/rochester-electronics-llc/74HCT390N-652/11530968) | digikey | baixa | 6.45 | 19.35 | 141.85
display bcd catodo comum | 2 | link (https://www.smartkits.com.br/display-de-7-segmentos-catodo) | smatkits | alta | 2.9 | 5.8 | 147.65
display bcd anodo comum | 2 | link (https://www.smartkits.com.br/display-de-7-segmentos-5161bs) | smartikits | baixa | 2.9 | 5.8 | 153.45
Mc14495 | 2 | não tem | não achei |  |  | 0 | 153.45
uln2803a | 2 | link (https://www.digikey.com.br/pt/products/detail/stmicroelectronics/ULN2803A/599591) | digikey | alta | 9.06 | 18.12 | 171.57
trimpot | 7 | link (https://www.smartkits.com.br/trimpot-3296w-10k-25-voltas) | smartkits | alta | 1.8 | 12.6 | 184.17
led 5mm | 15 | link (https://www.smartkits.com.br/led-difuso-5mm-vermelho) | smartikits | alta | 0.2 | 3 | 187.17
diodo | 30 | link (https://www.smartkits.com.br/diodo-retificador-1n4007) | smartkits | baixa | 0.2 | 6 | 193.17
resistor pull up | 5 | link (https://www.digikey.com.br/pt/products/detail/bourns-inc/4610X-101-103LF/1089169) | digikey | alta | 2 | 10 | 203.17
arduino nano | 1 | link (https://www.smartkits.com.br/placa-nano-v3-0-cabo-usb-arduino-compativel) | smartkits | alta | 29.9 | 29.9 | 233.07
jumper m/m | 1 | link (https://www.smartkits.com.br/kit-jumpers-u-140-unidades) | smartikits | media | 13.9 | 13.9 | 246.97
resistor 220 | 20 | link (https://www.smartkits.com.br/resistor-270r-14w-5-10-unidades) | smartkits | media | 0.07 | 1.4 | 248.37
resistor 1k | 10 | link (https://www.smartkits.com.br/resistor-1k-2w-5) | smartkits | media | 0.03 | 0.3 | 248.67
resistor 4.7k | 10 | link (https://www.smartkits.com.br/resistor-4k7-14w-5-10-unidades) | smartkits | media | 0.07 | 0.7 | 249.37
resistor 6.8k | 10 | link (https://www.smartkits.com.br/componentes/resistores/resistor-18w/resistor-6-8k-18w-5-10-unidades) | smartkits | media | 0.07 | 0.7 | 250.07
resistor 15k | 20 | link (https://www.smartkits.com.br/resistor-15k-14w-5-10-unidades) | smartkits | media | 0.07 | 1.4 | 251.47

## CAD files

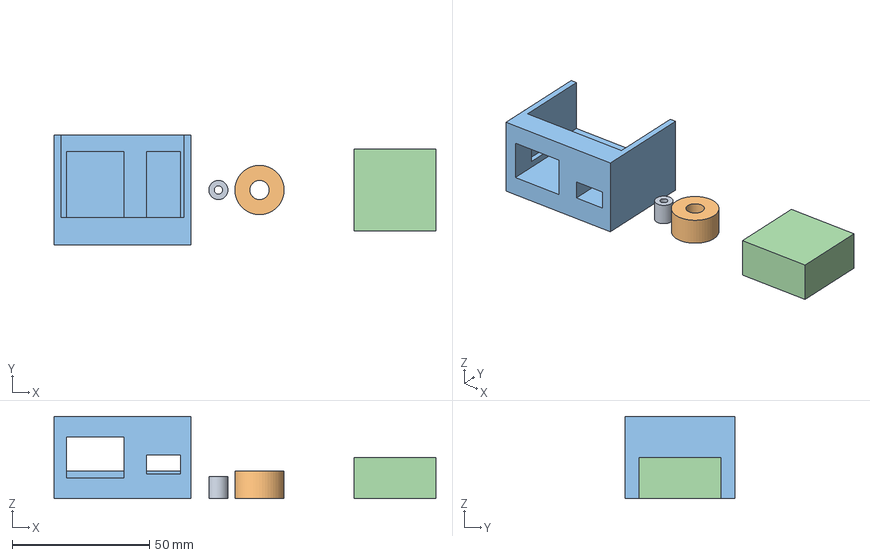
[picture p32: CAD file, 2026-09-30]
cad/BoxHoles.FCStd
139.4 x 40.0 x 30.0 mm
ScrewHole
Borne
Connectors
Testblock

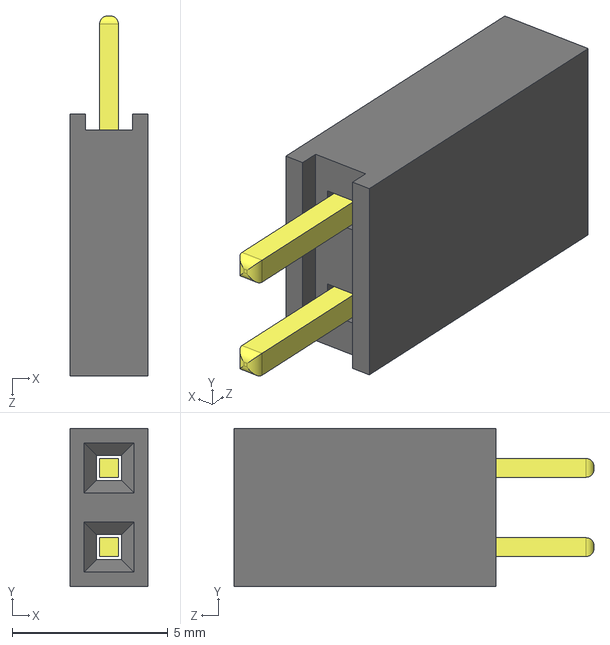
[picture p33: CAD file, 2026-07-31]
schematics/logic-board/pcb/placa de cima/componentes/1x2 female header/User Library-ZL262-2SG.STEP
2.50 x 5.08 x 11.6 mm

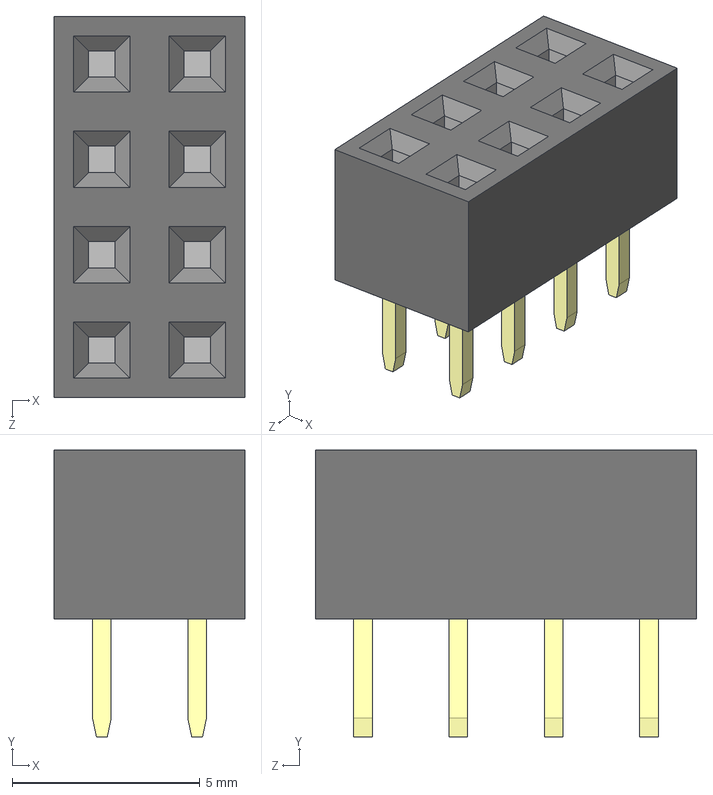
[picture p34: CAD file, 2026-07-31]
schematics/logic-board/pcb/placa de cima/componentes/2x4 female header/User Library-2x4 female header 2_54mm pitch.STEP
5.08 x 7.65 x 10.2 mm

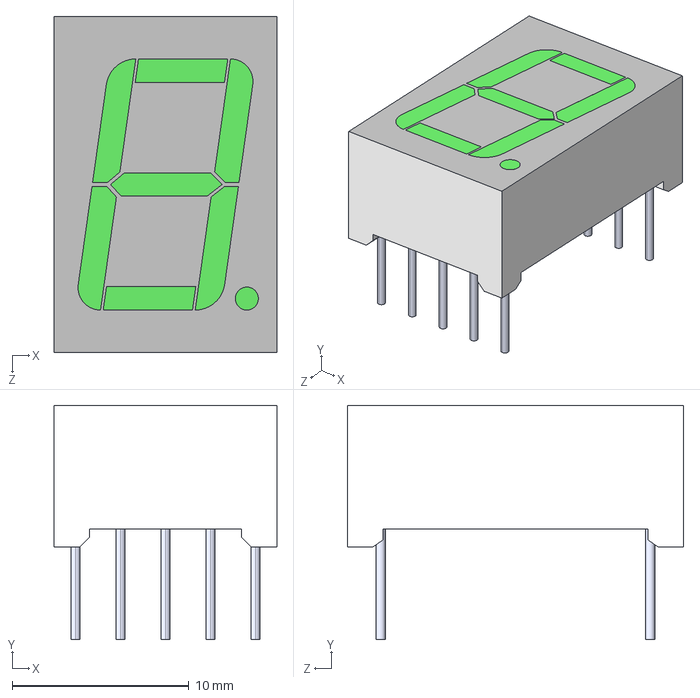
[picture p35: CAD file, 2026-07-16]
schematics/logic-board/pcb/placa de cima/componentes/LDS-C512RI--3DModel-STEP-510211.STEP
12.6 x 13.2 x 19.0 mm

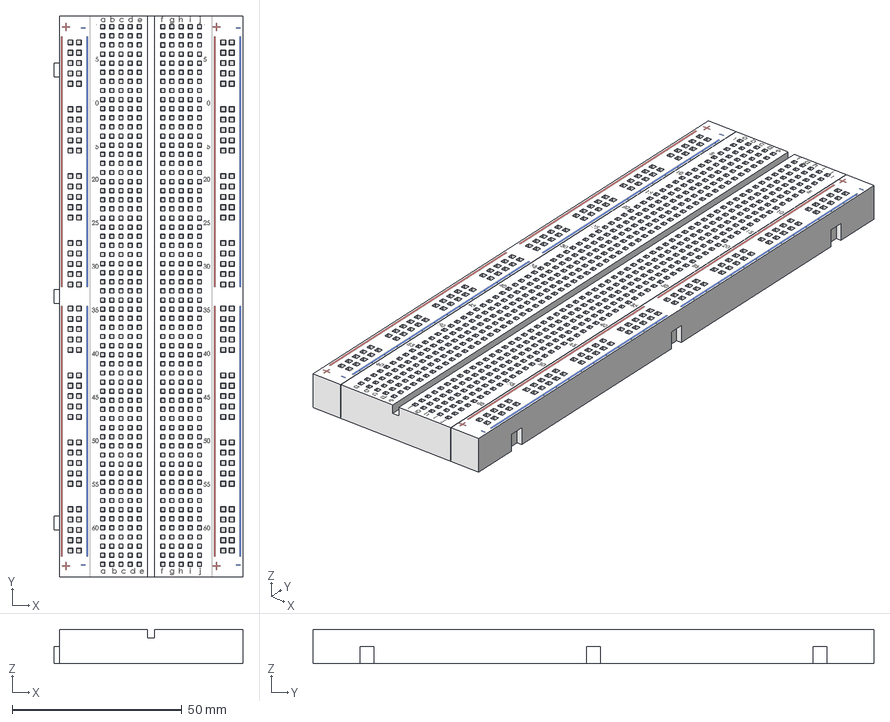
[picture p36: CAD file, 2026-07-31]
schematics/logic-board/pcb/placa de cima/componentes/protoboard-de-830-puntos-1.snapshot.3/proto_830.step
55.5 x 165.0 x 10.0 mm

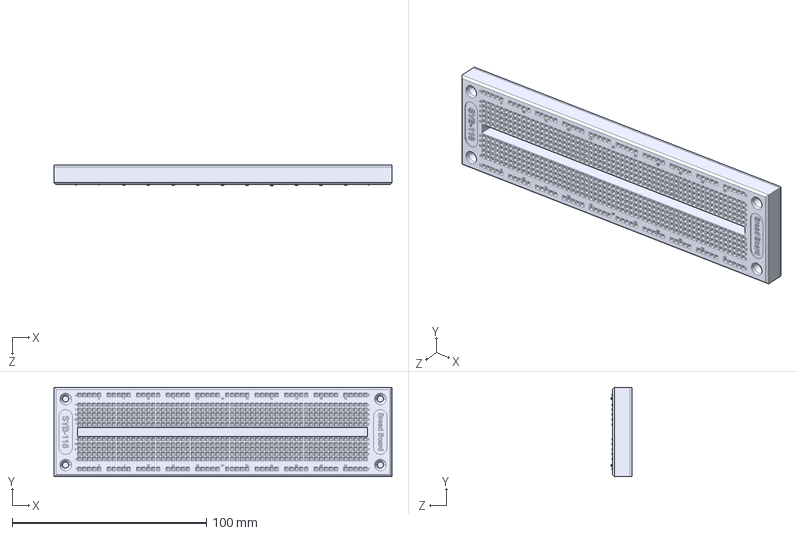
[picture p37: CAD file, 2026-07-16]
schematics/logic-board/pcb/placa de cima/componentes/protoboard/protoboard.STEP
174.0 x 46.0 x 10.6 mm

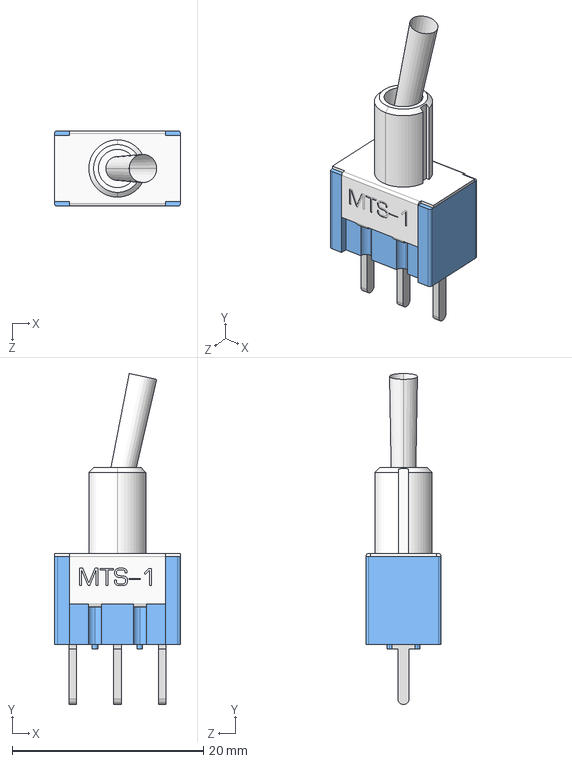
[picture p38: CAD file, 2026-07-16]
schematics/logic-board/pcb/placa de cima/step_chave.STEP
13.2 x 34.6 x 7.90 mm

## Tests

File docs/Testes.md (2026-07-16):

# Lista de Testes físicos do módulo de energia do Projeto

 - Testar cada trilha com uma carga, podendo ser um potenciômetro [X]
 - Testar todas as trilhas juntas com cargas [X]
 - Testar as trilhas +12V e -12V como alimentação para um amplificador operacional [X]
 - Testar a trilha de 5V como alimentanção para um microcontrolador [X]
 - Testar a trilha de 5V como alimentação para um microcontrolador junto com cargas (podem ser LEDs e CIs) [X]

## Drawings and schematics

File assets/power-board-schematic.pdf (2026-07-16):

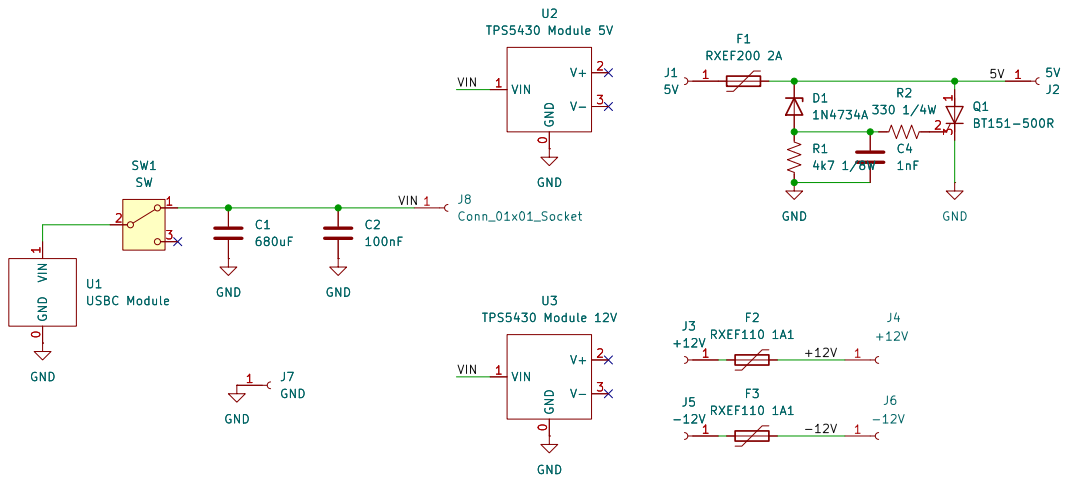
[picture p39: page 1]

By Arthur Damasceno
Sheet: /
File: digital-power-supply.kicad_sch
Title: Digital Electronics Power Supply

Size: A4 | Rev:
KiCad E.D.A. 10.0.4 | Id: 1/1

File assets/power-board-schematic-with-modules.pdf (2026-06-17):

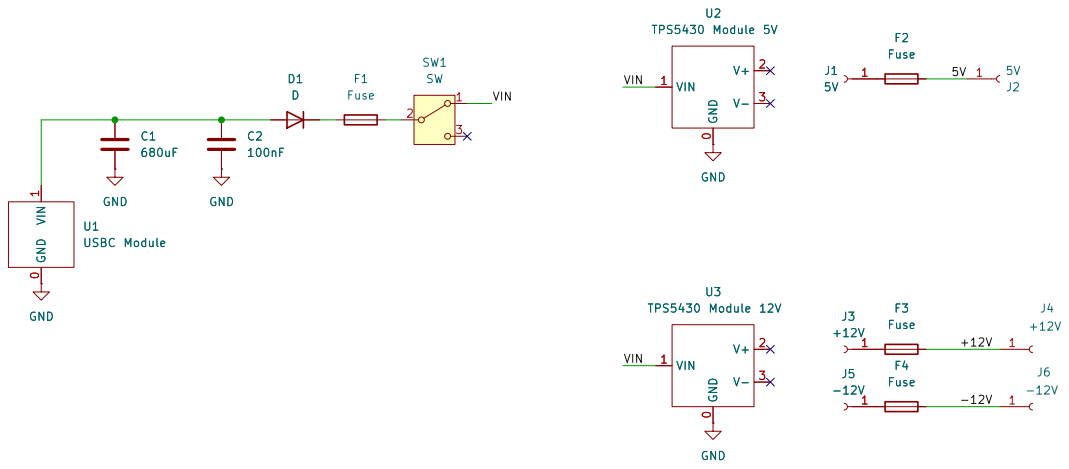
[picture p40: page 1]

Version with Modules
By Arthur Damasceno
Sheet: /
File: digital-power-supply.kicad_sch
Title: Projeto 8810 Power Supply Board

Size: A4 | Rev:
KiCad E.D.A. 10.0.3 | Id: 1/1

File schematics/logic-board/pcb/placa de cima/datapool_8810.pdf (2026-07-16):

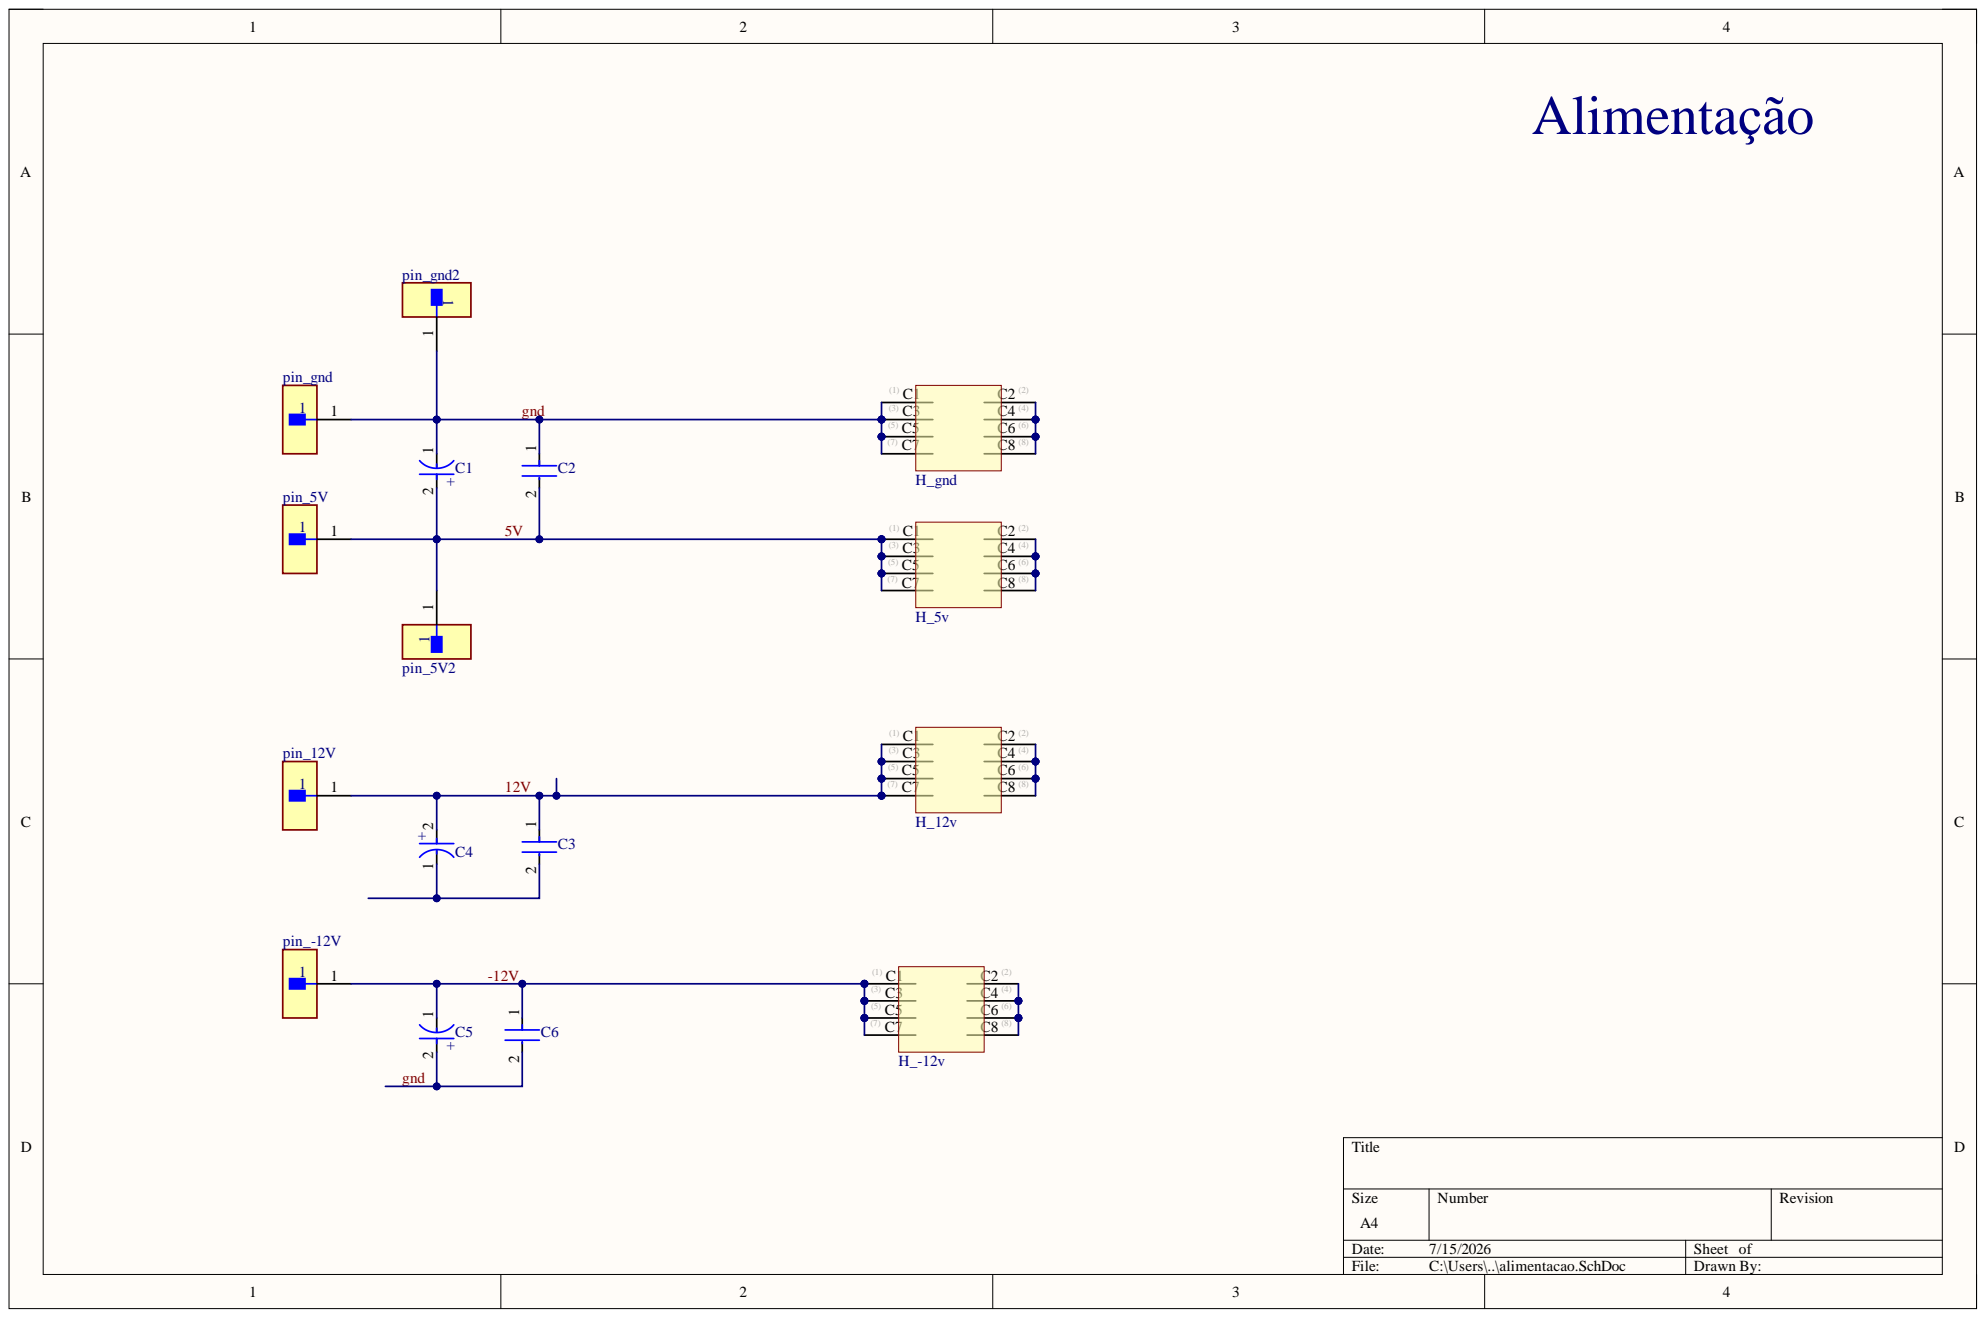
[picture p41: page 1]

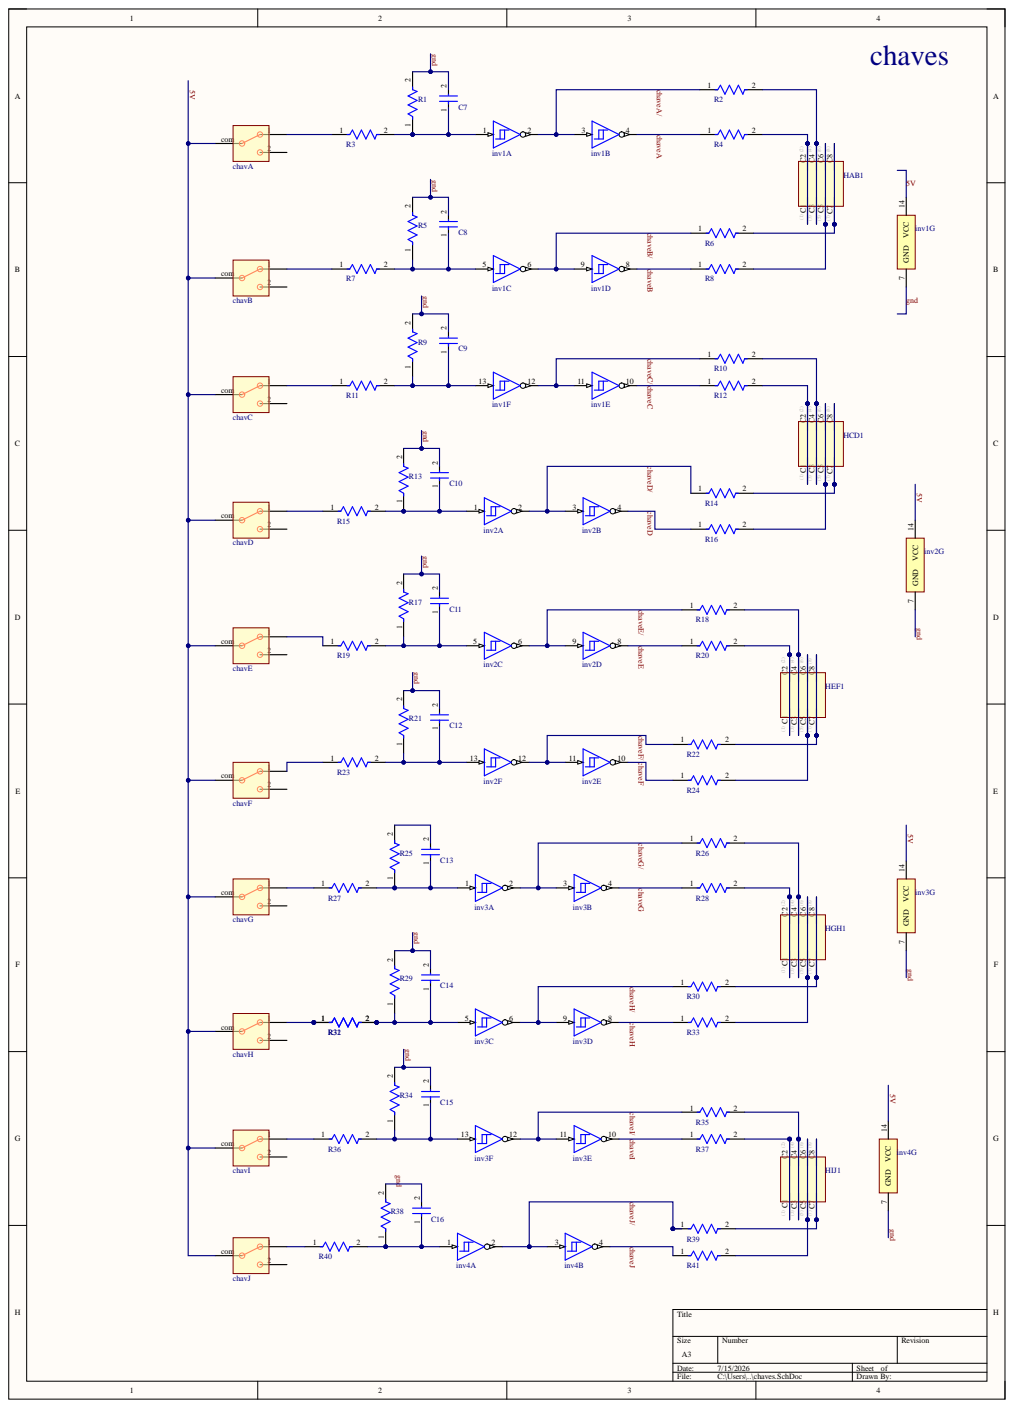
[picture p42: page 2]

chaveB/ chaveB chaveC/ chaveC

chaveE/ chaveE chaveF/ chaveF

Size A3 | Number | Revision

File: C:\Users\..\chaves.SchDoc | Drawn By:

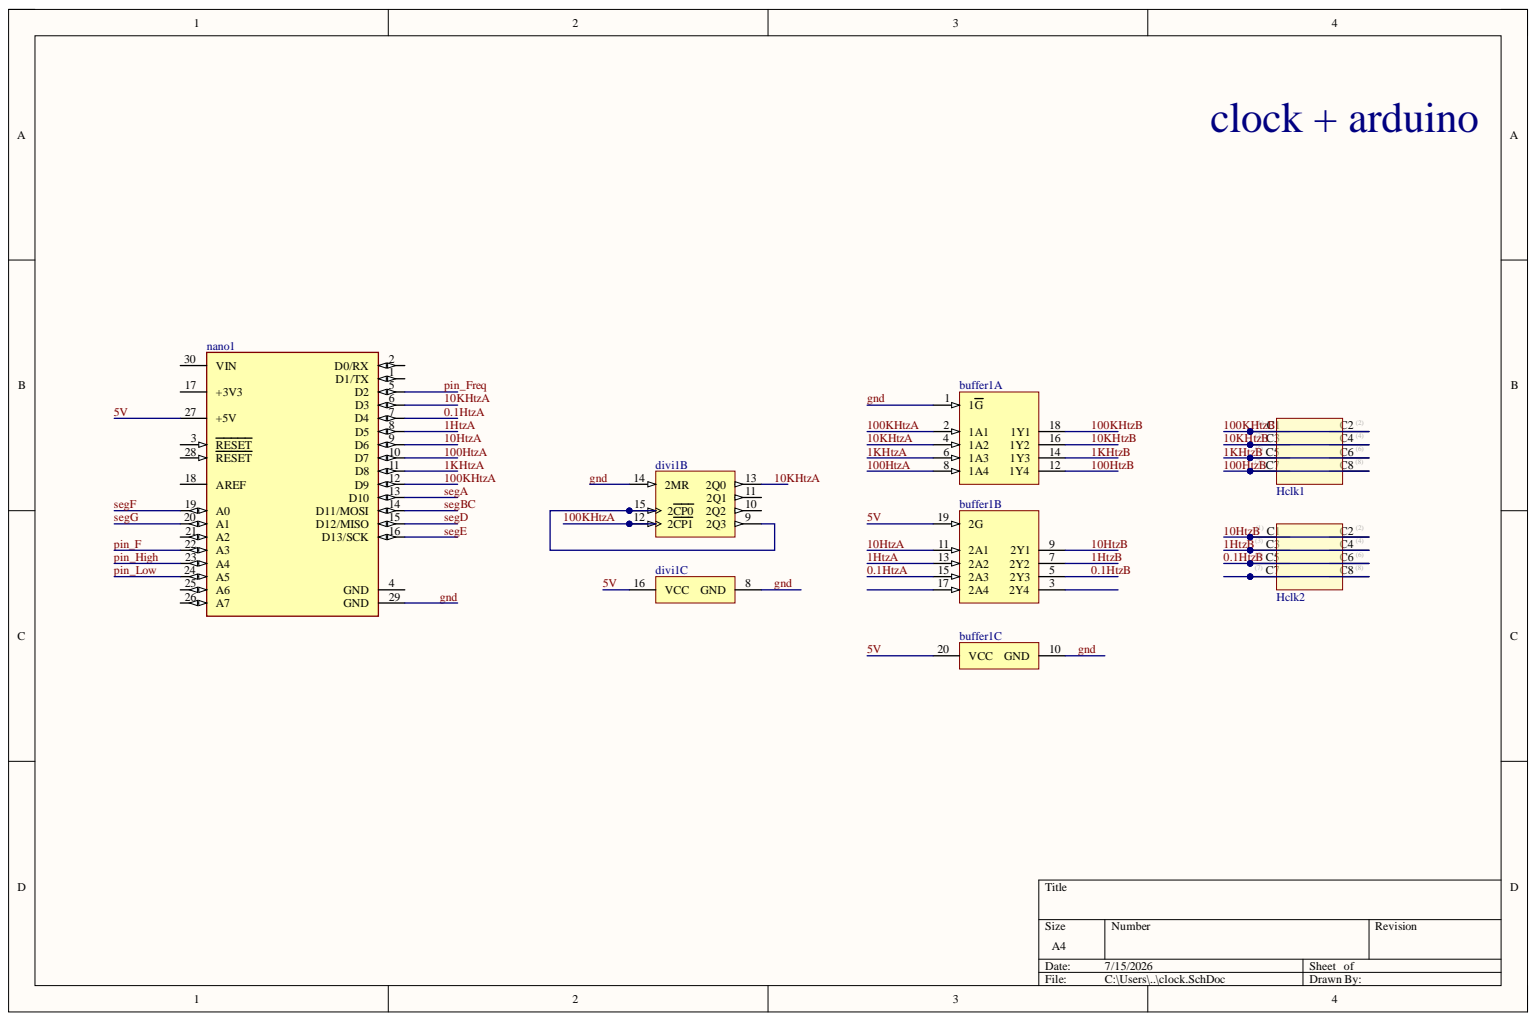
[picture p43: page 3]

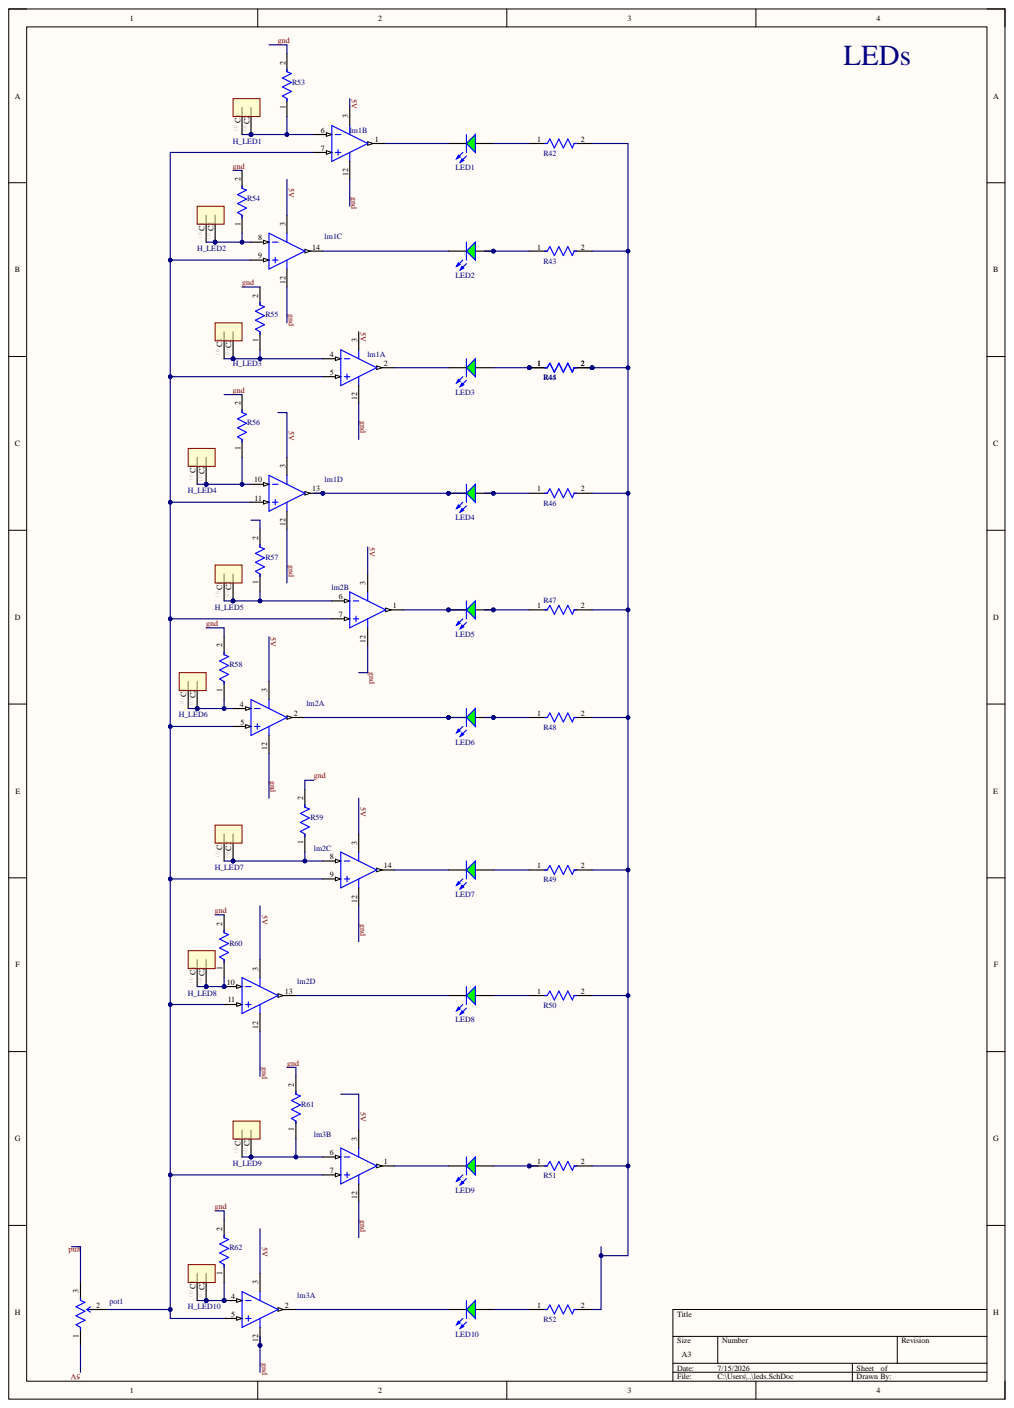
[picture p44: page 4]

Size A3 | Number | Revision

File: C:\Users\..\leds.SchDoc | Drawn By:

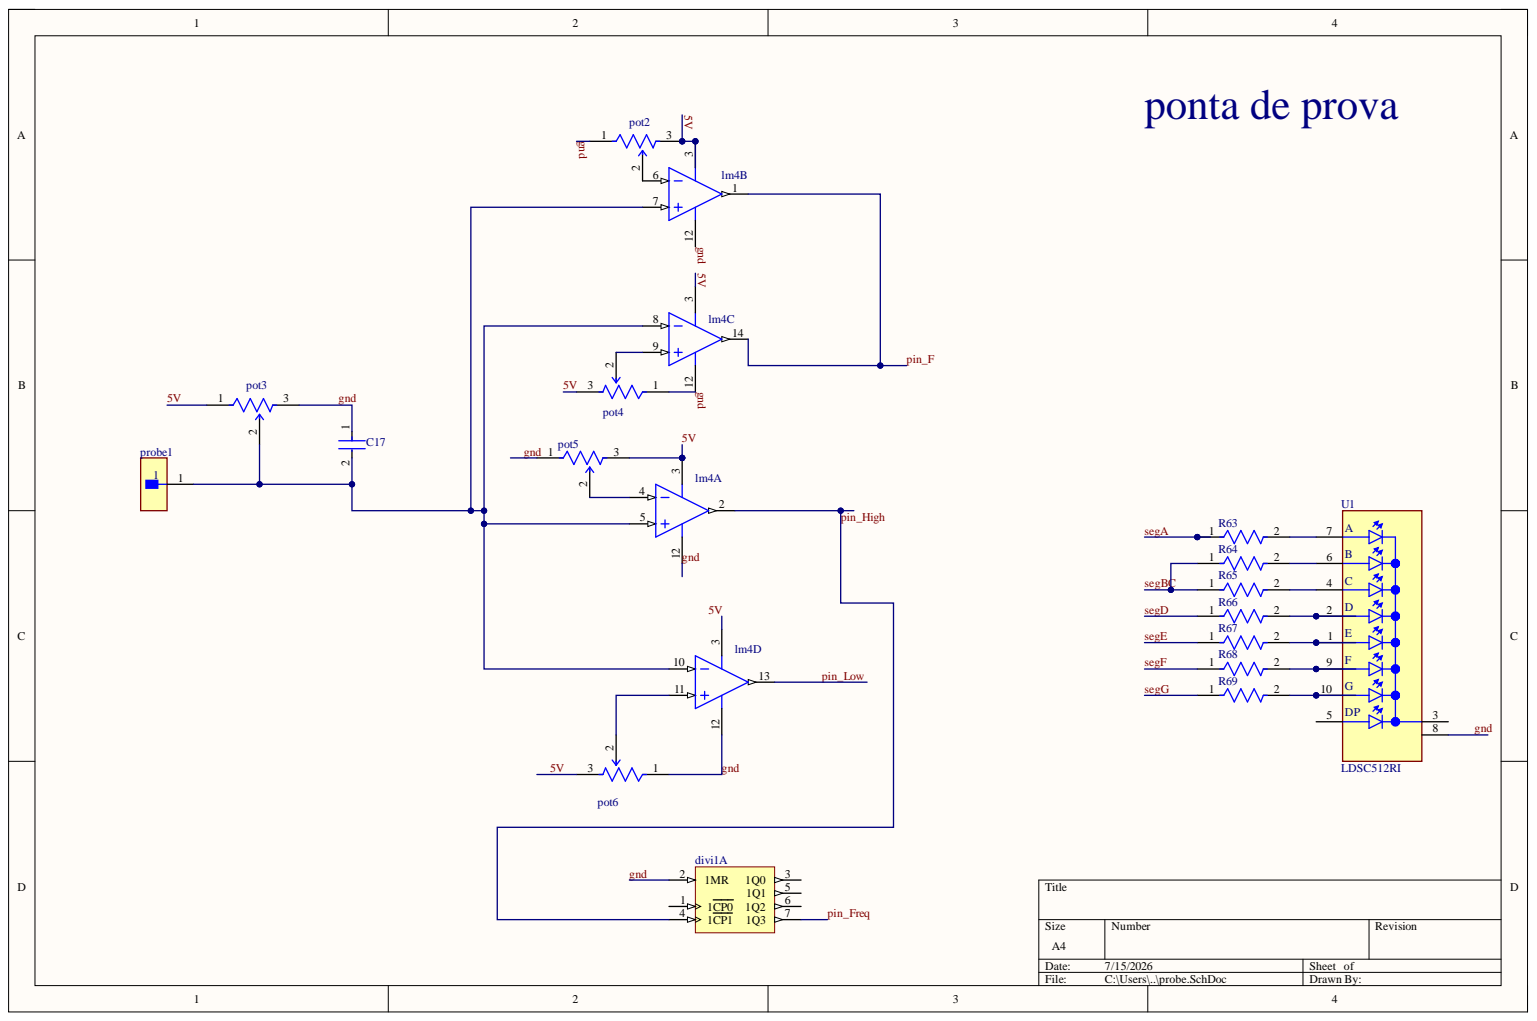
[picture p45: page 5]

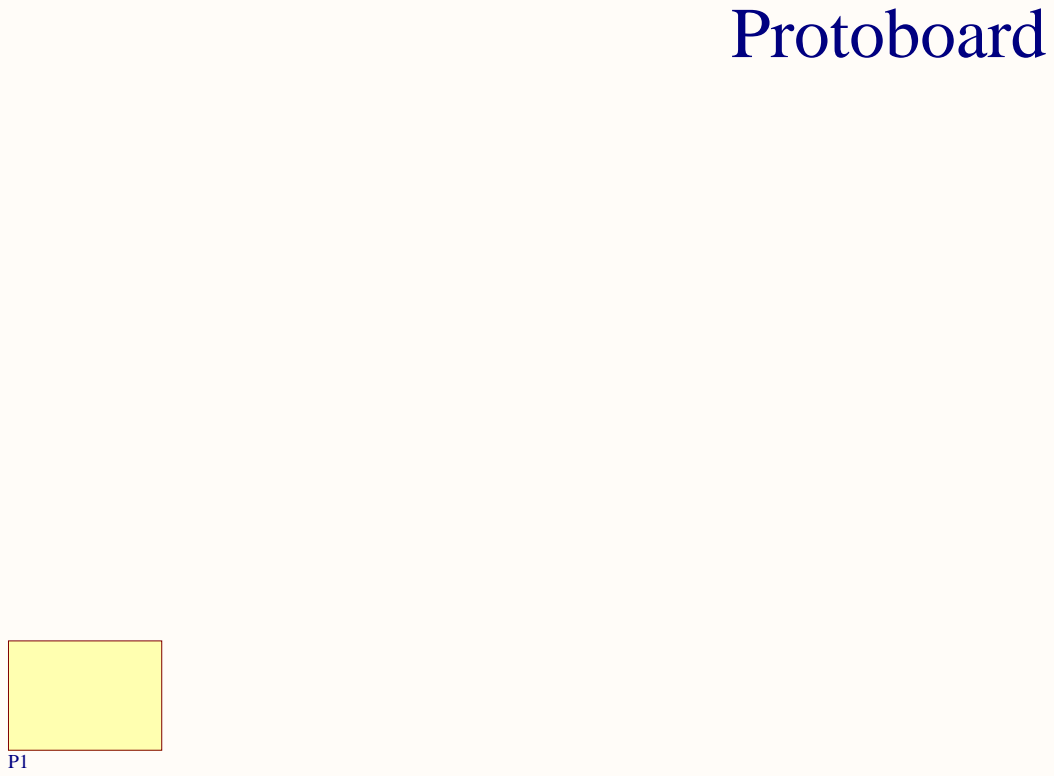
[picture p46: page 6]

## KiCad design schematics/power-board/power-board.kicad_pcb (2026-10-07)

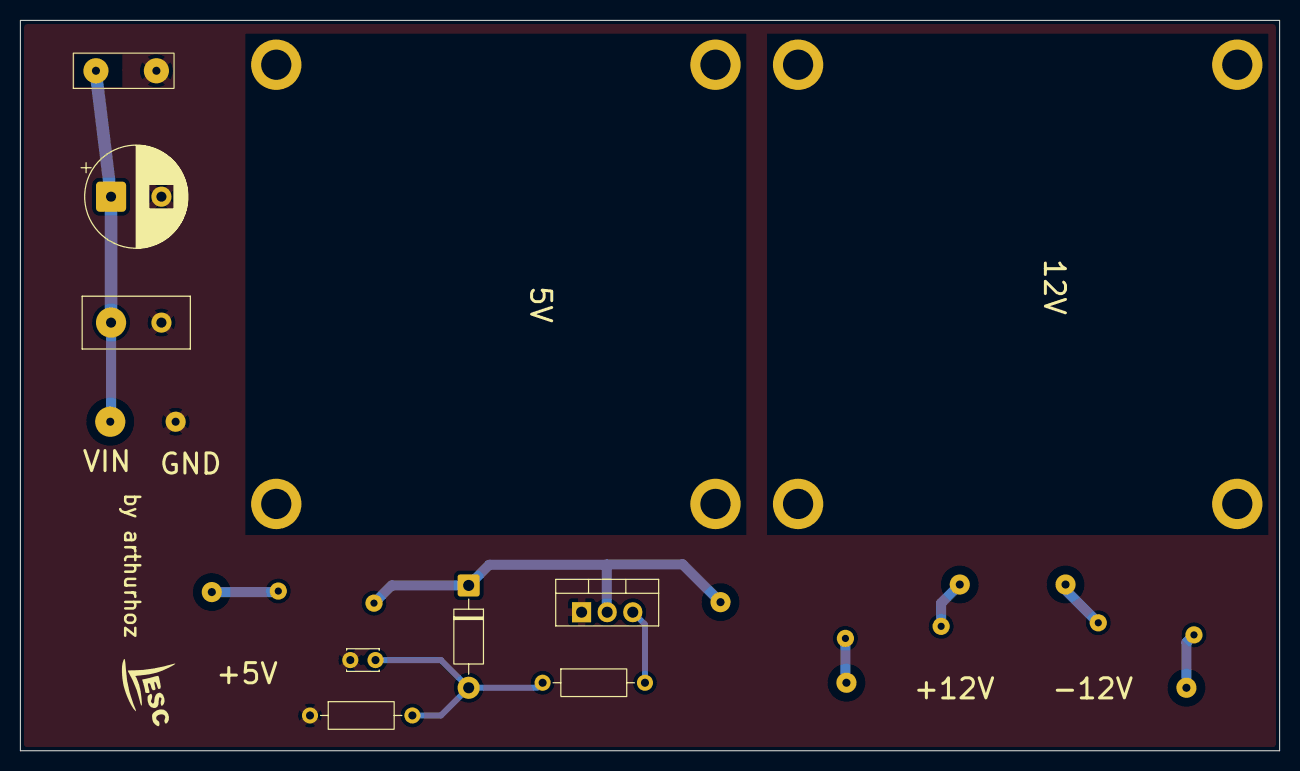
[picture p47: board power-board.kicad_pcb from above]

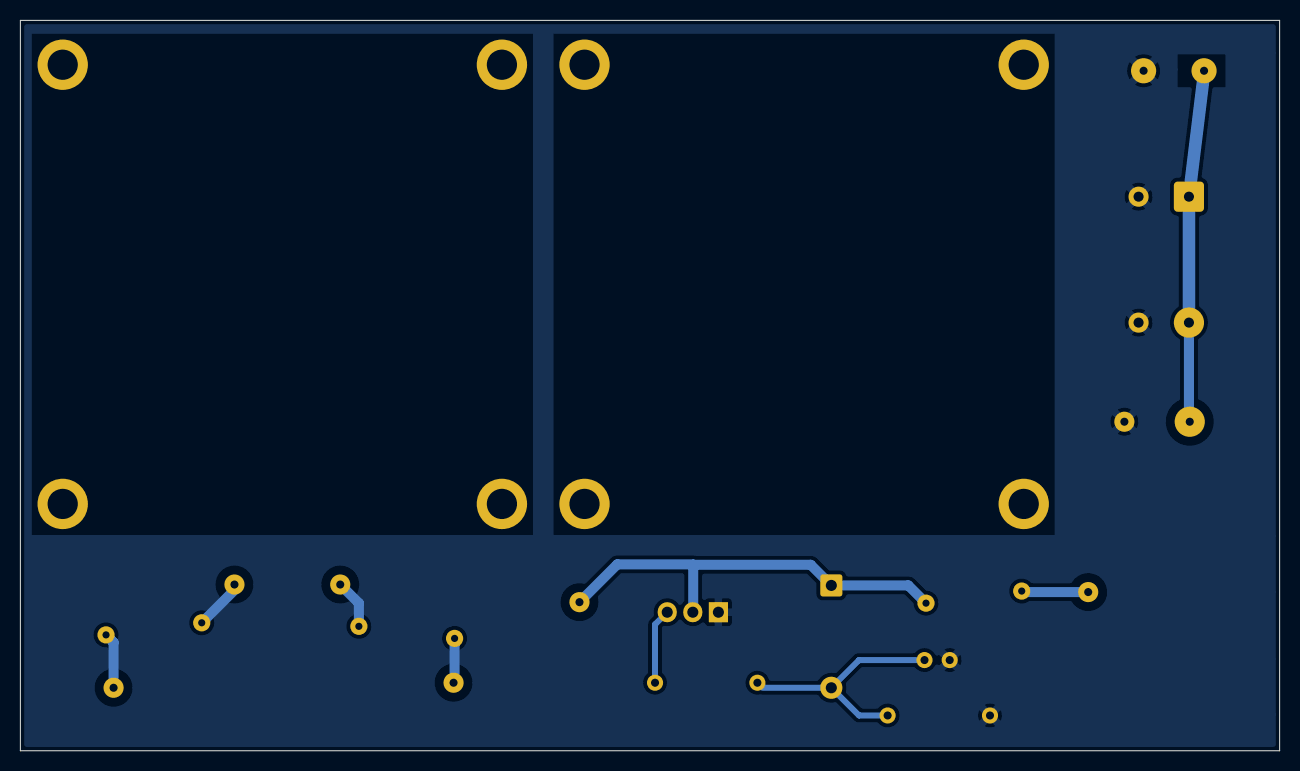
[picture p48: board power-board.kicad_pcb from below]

Board: 2 copper layers, 125.0 x 72.5 mm, 21 parts (2 on the bottom side), 8 nets.

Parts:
C1: 680uF; CP_Radial_D10.0mm_P5.00mm
C2: 100nF; C_Disc_D10.5mm_W5.0mm_P5.00mm
C4: 1nF; C_Disc_D3.0mm_W2.0mm_P2.50mm
D1: 1N4734A; D_DO-41_SOD81_P10.16mm_Horizontal
F1, F1#2, F1#3: Fuse; Fuse_Bourns_MF-RHT200
J1, J2: 5V; Connector
J3, J4: +12V; Connector
J5, J6: -12V; Connector
J7: GND; ConnectorGND
J8: Conn_01x01_Socket; Connector
Q1: BT151-500R; TO-220-3_Vertical
R1: 4k7 1/8W; R_Axial_DIN0207_L6.3mm_D2.5mm_P10.16mm_Horizontal
R2: 330 1/4W; R_Axial_DIN0207_L6.3mm_D2.5mm_P10.16mm_Horizontal
U1: USBC Module; USBC_Module
U2: TPS5430 Module 5V; TPS5430_Module
U3: TPS5430 Module 12V; TPS5430_Module

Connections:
/5V: D1.1 (K), F1.2, J2.1 (Pin_1_1), Q1.2 (G)
/+12V: F1#3.1, F1#3.2, J3.1 (Pin_1_1), J4.1 (Pin_1_1)
/-12V: F1#2.1, F1#2.2, J5.1 (Pin_1_1), J6.1 (Pin_1_1)
/VIN: C1.1, C2.1, J8.1 (Pin_1_1)
GND: C1.2, C2.2, C4.2, J7.1 (Pin_1_1), Q1.1 (A), R1.1, U1.0 (GND)
unnamed: C4.1, D1.2 (A), R1.2, R2.1
unnamed: F1.1, J1.1 (Pin_1_1)
unnamed: Q1.3 (K), R2.2

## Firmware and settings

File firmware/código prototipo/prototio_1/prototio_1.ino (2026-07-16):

//-------------------------------------------
//PONTA DE PROVA
//-----------------------------------------
//-------------------------------------------
//definições para ponta de prova
//-----------------------------------------

#define pin_Low 17
#define pin_High 18
#define pin_F 19
int high_stat;
int low_stat;
int f_stat;

//-------------------------------------------
//definições para frequencimetro
//-----------------------------------------


long leitura; // cria a variável tipo long
#define freq_l 2
#define t 100000
#define limite 40

//-------------------------------------------
//definições para BCD
//-----------------------------------------

int digito; //

#define F 5
#define A 4
#define C 3
#define V 2
#define T 6
 
byte displaySeteSeg[7][7] = { 
 //to juntando a parte da direita, o b e o c
 { 1,1,1,1,1,0},  //DIGITO 0
 { 0,1,0,0,0,0},  //DIGITO 1
 { 0,0,0,0,0,0}, //vaziio
 { 1,0,1,1,1,0},    //C
 { 1,1,0,1,1,1},    //A
 { 1,0,0,1,1,1},    //F
 { 1,1,1,1,1,1}     //tudo 
};
 
int pin_BCD[6] = {16, 15, 12, 11, 13, 14};


//-------------------------------------------
//  CLOCK
//-----------------------------------------
//-------------------------------------------
//definições para frequencia output
//-----------------------------------------

//pino de interrupção
#define Interrupt_pin 3

//saida da frequencia
#define pin_100k 9
#define pin_10k 4
int cont_1k = 5; 
#define pin_1k 5
int cont_100 = 10; 
#define pin_100 6
int cont_10 = 10; 
#define pin_10 7
int cont_1 = 10; 
#define pin_1 8
int cont_01 = 10; 
#define pin_01 10 






void setup() {
  Serial.begin(9600);

  //-------------------------------------------
  //PONTA DE PROVA
  //ponta de prova
  pinMode(pin_Low, INPUT_PULLUP); 
  pinMode(pin_High, INPUT_PULLUP); 
  pinMode(pin_F, INPUT_PULLUP); 
  pinMode(freq_l, INPUT_PULLUP); 
 
  //BCD
  pinMode(pin_BCD[0], OUTPUT);
  pinMode(pin_BCD[1], OUTPUT);
  pinMode(pin_BCD[2], OUTPUT);
  pinMode(pin_BCD[3], OUTPUT);
  pinMode(pin_BCD[4], OUTPUT);
  pinMode(pin_BCD[5], OUTPUT);

  //inicializa display vazio
  digito = V;
  ligaSegmentosDisplay(digito);


  //-------------------------------------------
  //CLOCK
  //---------------------------------
  //configurando pinos de frequencia
  pinMode(pin_10k, OUTPUT);
  pinMode(pin_1k, OUTPUT);
  pinMode(pin_100, OUTPUT);
  pinMode(pin_10, OUTPUT);
  pinMode(pin_1, OUTPUT);
  pinMode(pin_01, OUTPUT);

  //---------------------------------
  //configurando interrupção
  cli();
  pinMode(Interrupt_pin, INPUT);
  attachInterrupt(digitalPinToInterrupt(Interrupt_pin), freq, RISING); //RISING

  //---------------------------------
  //configurando frequencia 100k
  pinMode(pin_100k, OUTPUT); // OC1A no Arduino Uno/Nano
  // Zera os registradores do Timer1
  TCCR1A = 0;
  TCCR1B = 0;
  TCNT1 = 0;
  // Modo CTC: conta até OCR1A e reinicia
  TCCR1B |= (1 << WGM12);
  // Toggle automático do pino OC1A, que é o D9
  TCCR1A |= (1 << COM1A0);
  // Sem prescaler: clock do timer = 16 MHz
  TCCR1B |= (1 << CS10);

  //OCR1A
  OCR1A = 79;
  sei();

}

void loop() {
    int pulse = (pulseIn(freq_l, HIGH, t))*2;
  leitura = (1000000 / pulse); 
  
  if(leitura >= limite){
    digito = C;
  }
  else{
    high_stat = digitalRead(pin_High);
    low_stat = digitalRead(pin_Low);
    f_stat = digitalRead(pin_F);

    if(high_stat == 1){
      digito = 1;
    }
    else if(low_stat == 1){
      digito = 0;
    }
    else if(f_stat == 1){
      digito = F;
    }
    else{
      digito = A;
    }
  }
  ligaSegmentosDisplay(digito);
}
 
void ligaSegmentosDisplay(byte digito){ 
  for (byte i = 0; i < 6; ++i){ 
    digitalWrite(pin_BCD[i], displaySeteSeg[digito][i]);
  }
}


//-------------------------------------------
//interrupção de tempo
//-----------------------------------------

void freq(){
  PORTD ^= (1<<PD4);
  
  if(--cont_1k == 0){
    PORTD ^= (1<<PD5);
    cont_1k = 5;
      
    if(--cont_100 == 0){
      PORTD ^= (1<<PD6);
      cont_100 = 10;
      
      if(--cont_10 == 0){
        PORTD ^= (1<<PD7);
        cont_10 = 10;

        if(--cont_1 == 0){
          PORTB ^= (1<<PB0);
          cont_1 = 10;

          if(--cont_01 == 0){
            PORTB ^= (1<<PB2);
            cont_01 = 10;
          } 
        }
      }
    
    }
  }
  
  
}

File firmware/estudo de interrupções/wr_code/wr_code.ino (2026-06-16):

/* =========================================================
   
   Curso de Arduino WR Kits
   Aplicação Profissional do Timer0 para bases de tempo

   Apoio: eletrogate.com 

   Autor: Dr. Eng. Wagner Rambo
   Data:  Novembro de 2021
 
========================================================= */


// =========================================================
// --- Interrupção ---
ISR(TIMER0_OVF_vect)
{
  static int baset1 = 0,           //variável local estática para base de tempo 1
             baset2 = 0;           //variável local estática para base de tempo 2
   
  TCNT0 = 0x06;                    //reinicializa Timer0

  //TEMPO de 1ms
  baset1 ++;                       //incrementa baset1 em 1 a cada ms
  baset2 ++;                       //incrementa baset2 em 1 a cada ms

  if(baset1 == 100)
  {
    //TEMPO de 1000ms
    baset1 = 0;                    //reinicia baset1
    PORTB ^= (1<<PORTB5);          //inverte o estado de digital 13 (PB5)
  
  } //end if

  if(baset2 == 741)
  {
    //TEMPO de 741ms
    baset2 = 0;
    //um segundo evento que será controlado a cada 741ms 
    
  } //end if

} //end ISR


// =========================================================
// --- Função Principal ---
int main()
{
  
  DDRB  |=  (1<<PORTB5);           //configura digital 13 (PB5) como saída
  PORTB &= ~(1<<PORTB5);           //inicializa digital 13 (PB5) em LOW
    
  cli();                           //desliga interrupções
  TCNT0  = 0x06;                   //inicia Timer0 para contar até 250
  TCCR0B = 0x03;                   //prescaler 1:64
  TIMSK0 = 0x01;                   //habilita interrupção do Timer0
  sei();                           //liga interrupções

  //BASE DE TEMPO PRINCIPAL = 62.5E-9 x 64 x 250 = 1ms

  while(1);                        //apenas aguarda interrupções
 
  return 0;                        //retorna 0 (precisa retornar algo, pois a função main é do tipo int)
 
} //end main


/* ============================================================================  
                                                              
                                       _                      
                                      / \                     
                                     |oo >                    
                                     _\=/_                    
                    ___         #   /  _  \   #               
                   /<> \         \\//|/.\|\\//                
                 _|_____|_        \/  \_/  \/                 
                | | === | |          |\ /|                    
                |_|  0  |_|          \_ _/                    
                 ||  0  ||           | | |                    
                 ||__*__||           | | |                    
                |* \___/ *|          []|[]                    
                /=\ /=\ /=\          | | |                    
________________[_]_[_]_[_]_________/_]_[_\_______________________________
                                                              
                                                              
============================================================================ */
/* --- Final do Programa --- */

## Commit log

2026-05-17 simulacoes completas
    [financeiro.xlsx]
2026-05-26 feat: add power supply board schematic
    [digital-power-supply.kicad_pcb, digital-power-supply.kicad_sch]
2026-06-02 docs: testes do módulo de energia
2026-06-16 adicionando os códigos do arduino
2026-06-17 feat: new schematic with modules and pcb creation
    [digital-power-supply.kicad_pcb, digital-power-supply.kicad_sch]
2026-06-24 skematico parte cima
    [8810.PcbDoc, 8810.SchDoc, LDS-C512RI--3DModel-STEP-510211.STEP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]
2026-07-15 skematico placa de cima
    [8810.PcbDoc, 8810.SchDoc, PcbLib1.PcbLib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]
2026-07-16 feat: new pcb design with crowbar overvoltage protection
    [digital-power-supply.kicad_pcb, digital-power-supply.kicad_sch]
2026-07-16 docs & fix: create schematics and pcb images and remove copper fill in tps modules zones
    [digital-power-supply.kicad_pcb]
2026-07-19 feat: increase tracks width and add zone rules
    [digital-power-supply.kicad_pcb, digital-power-supply.kicad_sch]
2026-07-23 docs: add power board documentation
    idk
2026-07-31 feat: add 3d module model
    [digital-power-supply.kicad_pcb, digital-power-supply.step]
2026-07-31 acabar a pcb de cima
    [8810.GBL, 8810.GBO, 8810.GBP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]
2026-07-31 feat: add box holes for screws
2026-08-07 docs: add README for the project and refactor folders
    [.kicad_sch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]
2026-08-17 fix: move vias to back plane
    [power-board.kicad_pcb]
2026-09-07 Salva meu trabalho antes da reorganização
    [8810.GBL, 8810.GBO, 8810.GBP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]
2026-09-15 feat: create temp holes in CAD project Box for reference
    [BoxHoles.FCStd]
2026-09-30 refactor: fix PCBBox holes dimensions and remake pcb vias with the new components
    [BoxHoles.FCStd, power-board.kicad_pcb, power-board.kicad_sch]
2026-10-06 feat: make mechanical holes eletrical and redo the Box
    [power-board.kicad_pcb]
2026-10-07 fix: pin width of 12 Volt
    [power-board.kicad_pcb]
2026-10-27 feat: PCBBox improvements and PartGuard creation for Pins
